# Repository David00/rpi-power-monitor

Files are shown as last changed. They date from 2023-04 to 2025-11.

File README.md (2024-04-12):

# Power Monitor HAT (for Raspberry Pi)

This project is a combination of custom hardware and software that will allow you to monitor your unique power situation in real time, including accurate consumption, generation, and net-production. The data are stored to a database and displayed in a Grafana dashboard for monitoring and reporting purposes.

This project is derived from and inspired by the resources located at https://learn.openenergymonitor.org. 

---

## Where can I get it?

I am offering DIY kits, factory-assembled PCBs, and a variety of current transformers to use with this project.

Please see https://power-monitor.dalbrecht.tech/ for more information.

---

## How do I install?

There are two main ways to install - either flash the custom OS image to your microSD card, or perform the manual installation process on your existing image. Both processes are documented here:

See [Software Installation](https://david00.github.io/rpi-power-monitor/docs/general/install-the-software.html#prebuilt-os-image) in the docs.

After installation, see the [configuration section](https://david00.github.io/rpi-power-monitor/docs/v0.3.0/configuration.html) in the docs for further information on setting up the power monitor.

---

## What does it do?

This code accompanies DIY circuitry that supports monitoring of up to 6 current transformers and one AC voltage reading. The individual readings are then used in calculations to provide real data on consumption and generation, including the following key metrics:

* Total home consumption
* Total solar PV generation
* Net home consumption
* Net home generation
* Total current, voltage, power, and power factor values
* Individual current transformer readings
* Harmonics inspection through a built in snapshot/plotting mechanism.

The code takes tens of thousands of samples per second, corrects for phase errors in the measurements, calculates the instantaneous power for the tens of thousands of sampled points, and uses the instantaneous power calculations to determine real power, apparent power, and power factor. This means the project is able to monitor any type of load, including reactive, capacitive, and resisitve loads.

---

## Documentation

https://david00.github.io/rpi-power-monitor/docs/general/index.html

---

## Contributing

Would you like to help out? Shoot me an email at github@dalbrecht.tech to see what items I currently have pending.

---

### Credits

* [OpenEnergyMonitor](https://openenergymonitor.org) and forum member Robert.Wall for guidance and support

* The `spidev` project on PyPi for providing the interface to read an analog to digital converter

---

### Like my project? Donations are welcome!



BTC:  1Go1YKgdxAYUjwGM1u3JRXzdyRM938RQ95

###### Last Updated:  April 2023

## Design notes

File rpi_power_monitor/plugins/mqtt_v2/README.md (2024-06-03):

# MQTT Documentation

#### Author: jplord, based on jmadden91 v1 implementation

## Purpose

The MQTT plugin allows you to export power monitor data to a MQTT-capable system. 

## Setup & Usage
You'll need to install the paho mqtt v2 client to use this plugin:

    pip install paho-mqtt>=2

The following configuration block needs to be added to the power monitor's `config.toml` file

```toml

[plugins.mqtt_v2]
    enabled = true
    host = "xxx.xxx.xxx.xxx"
    # Leave Username and Password "" if you are not using authentification
    username = ""
    password = ""
    prefix = "powermon"
    power_change = 5
    voltage_change = 3
    current_change = 1
    pf_change = 0.05
    refresh_rate = 5 # Refresh rate in seconds
    max_publish_seconds = 600

```

This plugin will send all measurements for all channels to the host specified above.
Alter power_change, voltage_change, current_change, pf_change to define how much variation in the values will trigger a publish
Alter max_publish_seconds to define how often values are republished regardless of variation

## Configuration options

    enabled

Needs to be set to true to enable the plugin.

    username
    password

Specify the required username and password for MQTT. Leave "" if you are not using MQTT authentification.

    prefix

Specify the prefix of the mqtt topic used to publish the values.

    power_change
    voltage_change
    current_change
    pf_change

Define these values to determine the required variation in power, voltage, current or pf that will force an MQTT publish of the new value if detected over a period of less than the configured max_publish_seconds.
For example, with a configuration of voltage_change = 3, if the voltage is stable at 122.00 volt and it drops to 118.00 volt over a period of time that is less than the configured max_publish_seconds, the 118.00 volt value will be published to MQTT immediately and as soon as detected as it is a delta of 4 volt which is greater than the configured 3 volt. The same would occur if 118.00 volt is measured and an increase to 122.00 volt occurs over a time period of less than max_publish_seconds.

    max_publish_seconds

Define this value to force a publish of the refreshed and most up to date values of all measurements regardless of if they changed of not.

    refresh_rate

How often this plugin will read current values from the samples provided by rpi-power-monitor.

## Support
Please post any issues or questions in the pull request thread located here:

https://github.com/David00/rpi-power-monitor/pull/124

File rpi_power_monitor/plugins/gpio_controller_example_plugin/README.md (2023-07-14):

# GPIO Controller Documentation

#### Author: David00

## Purpose
The GPIO Controller serves mainly as an example plugin to demonstrate how to build a plugin for this project.  However, it is a fully functional plugin, and as written, it will perform the following functions:

* Setup a single pin as an INPUT
* Setup a single pin as an OUTPUT
* Every 1 minute, set the output pin to 1/high if the power monitor's measurements are reporting a net-export of power.
* Every 1 minute, set the output pin to 0/low if the power monitor's measurements are reporting a net-import of power.

## Setup & Usage
This plugin requires RPi.GPIO to work. You can install it with the following command:
    
    pip install RPi.GPIO

The following configuration block needs to be added to the power monitor's `config.toml` file:

```toml
[plugins.gpio_controller_example_plugin]
    enabled = true
    pin_numbering_scheme = 'BCM'
    output_pin = 17
    input_pin = 27
    # Optional Config settings
    # log_level = 'INFO'  # This will override the logging level for the plugin, which normally gets the logging level from the main program.  
```

The input and output pins can use the "BCM" or the "BOARD" scheme. Here's the difference:

* BCM uses the "GPIO #" syntax: usually GPIO 1 through GPIO 26.
* BOARD uses the actual pin number on the header: 1 - 40

_See the "What do these numbers mean?" section on https://pinout.xyz/ for more info, and for a detailed header pinout map._

## Modifications
This plugin is a barebones example of how to write a plugin. Therefore, the actual logic of the plugin is fairly simple and may require modification to meet the needs of various users.  The entire logic of the plugin is contained inside [a `while` loop](https://github.com/David00/rpi-power-monitor/blob/develop/v0.3.0-plugins/rpi_power_monitor/plugins/gpio_controller_example_plugin/gpio_controller_example_plugin.py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) - this is where the decision is made to change the state of the output pin and is the likely place for you to expand the functionality of the plugin.

## Support
Please use [GitHub Discussions](https://github.com/David00/rpi-power-monitor/discussions) if you have questions about using or modifying this plugin.

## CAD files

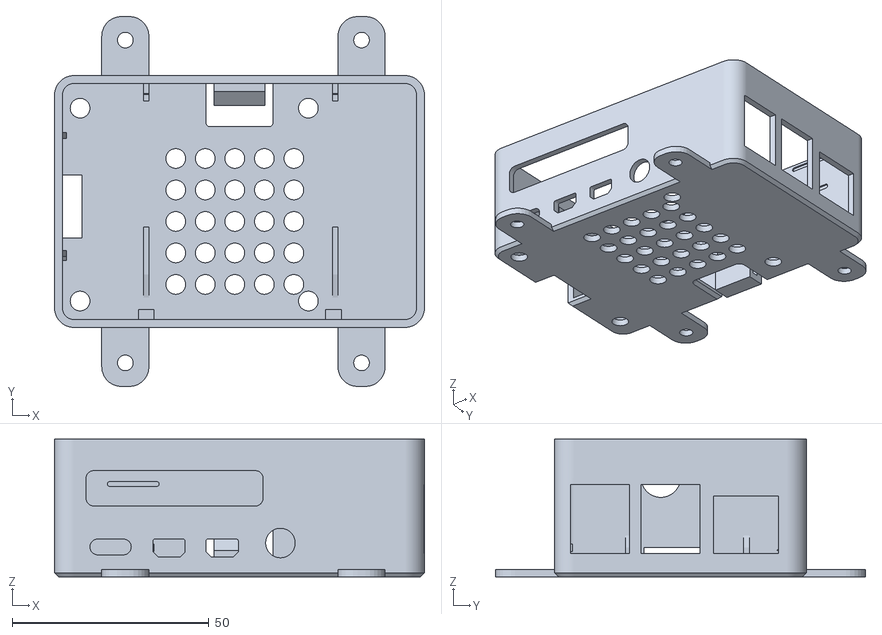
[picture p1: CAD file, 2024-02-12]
cases/factory-assembled-pcb/pi4/aircooled-jpl/factory-assembled-hat-pi4-box.stl
94.0 x 94.0 x 35.0

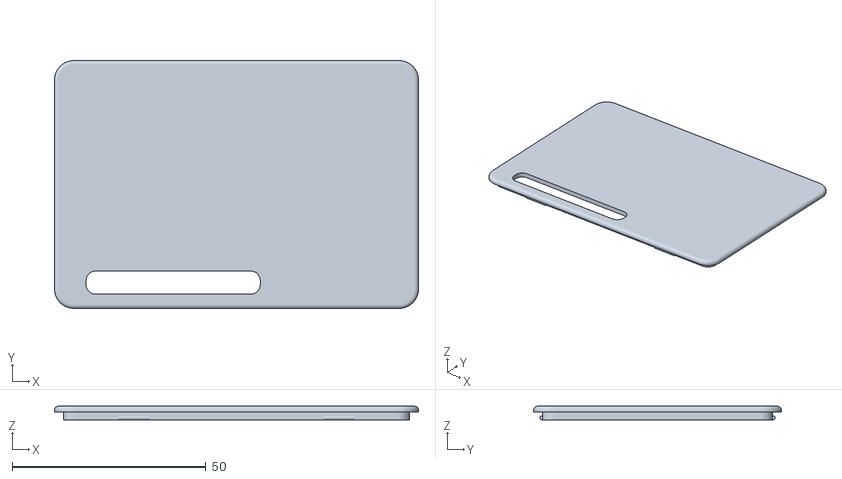
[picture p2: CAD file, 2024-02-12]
cases/factory-assembled-pcb/pi4/aircooled-jpl/factory-assembled-hat-pi4-cover.stl
94.0 x 64.0 x 3.50

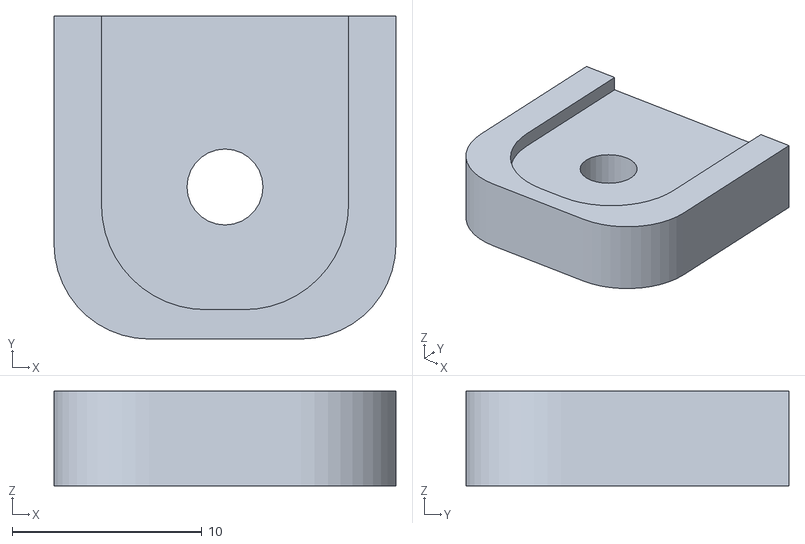
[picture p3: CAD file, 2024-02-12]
cases/factory-assembled-pcb/pi4/aircooled-jpl/factory-assembled-hat-pi4-standoffs.stl
18.0 x 17.0 x 5.00

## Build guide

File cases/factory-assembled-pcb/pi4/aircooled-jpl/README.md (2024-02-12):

# Case for Power Monitor HAT factory assembled for the Raspberry Pi 4 Model B

This is a case you can print for the factory assembled HAT running on a Raspberry Pi 4 Model B

---

## Features

The case includes holes for the standard Pi 4 Model B ports and in addition side holes that match those on the HAT. Also, the cover features an opening for the top screws of the terminal block.

Standoffs can be printed to raise the case off the surface it is installed on.

Tight clip fitment for the Raspberry Pi. It will be hard to remove the project from the case once clipped in place. Make sure the hat and any required heat sinks on the Pi are installed prior to fitting it into the case. It is also recommended to install the metal standoffs for the hat and insert the Pi without the hat installed.
---

## How to print ?

I have tested the build on Flash Forge Adventurer 4.

Supports are required for the case. Don't forget under the protruding clips near the USB C and audio port of the Pi. I used 4 sheels and 100% infill.

The standsoffs can be glued using a drop of crazy glue.

Case design based on https://www.printables.com/model/116513-another-raspberry-pi-4-case/files by guytas

###### Last Updated:  February 12 2024

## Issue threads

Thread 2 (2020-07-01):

I have got some issue

Riri45, 2020-07-01:
The adc which is mcp3008 is overheated, I am not using pcb, I use your early method at https://community.openenergymonitor.org/t/diy-current-monitor-on-raspberry-pi-my-power-calculation-isnt-accurate-help-please/13266/50 by using breadboard and gpio breakout broad, did the post installation setup until the "file written"

David00, 2020-07-01:
Hi Riri45, can you elaborate on the actual issue? What exactly isn't working with your breadboard circuit?

Riri45, 2020-07-01:
Sorry for not being clear at first
I have some questions
1.is it normal for the ADC overheat?
2.
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
The adc does not showing any data, I think I might damage my adc due to overheat

David00, 2020-07-01:
The MCP3008's datasheet says it is rated for operation up to 85 degrees Celsius, and I bet there is still quite a margin for operating in higher temps above 85C.  That's pretty warm! I'm not sure what you mean by overheat. Have you measured the temperature with an infrared temperature gun?

Make sure all your breadboard connections are correct, including the 4 required connections to the "control" side of the MCP3008 (power, ground, clock, and data).

Riri45, 2020-07-01:
sorry I forgot to ask is it okay if I'm using the opamp lm385 instead of lmV321

Riri45, 2020-07-01:
Problem solved the ADC is overheated due to my mistake connecting the t cobbler and the gpio cable wrongly at my raspberry pi, Thank you for sharing your knowledge, much appreciated

David00, 2020-07-01:
Great, glad you figured it out!

Riri45, 2020-07-12:
I would like to ask one more question if my input voltage is 230Vac compared to your input voltage 120Vac, at what are I should tweak in your phyton code?

David00, 2020-07-12:
I'm currently working on making the setup process easier for users to input values like this, along with the phase correction constants.  Right now there isn't actually a variable defined for source AC voltage. It's currently set as a ratio of your AC step down transformer multiplied by the ratio of the conditioning circuitry for the AC input (which is not very intuitive to figure out), but I've detailed the process below.

> I will be introducing a new "config.py" file for these values to be specified which should make the process easier, but it would be extremely helpful if you can do the following and confirm whether or not it works for your 230V input.

Find the ratio of your AC to AC step down transformer that puts out 9V AC. Ideally you should take an actual measurement of your A/C voltage source and then a measurement of your A/C transformer's output and do the following calculations based on that because the actual labels on the transformer itself usually aren't very accurate. Let's just say for this example that you measured 230V at the wall, and 9V at the transformer output:

1. Divide your transformer's output voltage by the grid voltage: 230/9 = 25.5556.
2. Multiply your answer by 11.  25.5556 * 11 = 281.111
    (11 is the ratio of the conditioning circuitry that the 9V AC source goes through on the PCB)

3. In [this line](https://github.com/David00/rpi-power-monitor/blob/master/power-monitor.py#L190) of the code, replace the `126.5` with `281.111`.

4. Uncomment [line 514](https://github.com/David00/rpi-power-monitor/blob/master/power-monitor.py#L514) so that the software prints the line voltage for every sample.

5. Save the file and restart your code - you should now see your line voltage readings printed out to your terminal window, and it should be in the area of 230V.  You'll still have to tune a bit for accuracy to improve the accuracy even further.

The accuracy tuning is a constant that is specified here [in line 39](https://github.com/David00/rpi-power-monitor/blob/master/power-monitor.py#L39).  You should compare a direct reading from your multi-meter to the printed Line Voltage message on the terminal. If the terminal is higher than the multi-meter, reduce the `AC_voltage_accuracy_factor` variable. If the terminal is lower than the multi-meter, increase the `AC_voltage_accuracy_factor`.

`AC_voltage_accuracy_factor` is just a constant that is multiplied by the calculated AC voltage. So, in my code, I needed a value of 1.075 for my AC voltage accuracy factor. That means my readings were a bit lower than my multi-meter, so 1.075 has the effect of increasing the calculated value by 7.5%.

Also, I have tried to find a 230V to 9V AC to AC transformer for 230V 50Hz grids and haven't found one. Can you please share the model number of the one you've acquired so we can help other users outside of the US?

Riri45, 2020-07-14:
sorry for a late reply, got some stuff needs to be done. https://www.aliexpress.com/item/4000276268327.html here is the link for the 230V/9V transformer.

i cannot access the influxdb and got some issue at the grafana resulting to this
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

David00, 2020-07-15:
Try to restart grafana with `docker restart grafana`.

If it continues to happen, can you share the output of `docker ps` and `docker logs grafana`?

Riri45, 2020-07-15:
Tried to run the influx docker but the `docker ps` showing this
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

Riri45, 2020-07-15:
Tried this too eventually resulting the same output
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

David00, 2020-07-15:
Something is running on your Pi that is using port 8086. You'll either have to figure out what it is and stop it, or change the port that the Docker influx container is binded to (and make the changes in the Python code to connect to the changed InfluxDB port).

Try this command on your Pi to see what is using 8086:

`sudo netstat -lntp | grep 8086`

Riri45, 2020-07-15:
I did and it shows this
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

Riri45, 2020-07-15:
managed to solved the influx issue but encounter with this
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

David00, 2020-07-17:
Have you ran the `power-monitor.py` file yet? [Running it for the first time](https://github.com/David00/rpi-power-monitor/wiki/Software-1.-Post-Installation-Setup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) will create the database.

Closed 2020-07-01.

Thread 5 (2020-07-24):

3 Phase Power

HarvsG, 2020-07-24:
Starting an issue to discuss the possibility (and perhaps track the progress) of supporting 3 phase power.

HarvsG, 2020-07-24:
We

1024jon, 2020-07-24:
+1 for me!

nannerbm60, 2020-07-24:
+1 for me too. Need mechanism for 3-phase monitoring with total consumption, total solar and net consumption

Nice work to date!

mario-correa, 2020-07-26:
+1

David00, 2020-07-26:
This is something I would love to work on, but I don't have a 3-phase supply to test and calibrate against.

If anyone has access to a lab grade 3-phase power supply and would like to assist with the development of 3-phase monitoring features, please send me an email at github@dalbrecht.tech.

fasmide, 2020-07-27:
This would be great and enable the project to be able to measure whole-house consumption across most European countries

As far as I know, the board would need at least 3 voltage measuring inputs for this to work...

i-am-snappy, 2020-08-04:
Just confirming that the 3 phase limitation is in software and not hardware? If that's the case, I'll be registering my interest on the board ASAP.

David00, 2020-08-04:
> Just confirming that the 3 phase limitation is in software and not hardware? If that's the case, I'll be registering my interest on the board ASAP.

The answer to your question is both yes and no. The code can be modified to _reasonably calculate_ 3-phase power usage, but there will be some small accuracy sacrifices. This is because, in the current single/split-phase implementation, there is only one voltage input sample, and the sample isn't just measuring the voltage level. It's also monitoring and capturing the harmonics of the voltage wave so that the current samples can be adjusted.

In a 3-phase system, each phase is **supposedly** offset by 120 degrees. With only one voltage input, we'd have to assume that this is true - we can't actually measure the offset to get its exact value. What if the real offset is 119.2 degrees? Or 121? These small tolerances will induce very small errors in the measurement and subsequent calculations. Yes, the variances I'm talking about here are a very small amount, but I am pointing it out just to say that in theory, it would not be as accurate as the current single/split-phase implementation is. I don't know how quantifiable this theoretical inaccuracy is, but I would take an educated guess and say that it would add an existing 1-2% accuracy variance.

In short, it's more of a software issue. The problem with assuming the phase difference and not being to measure it a rather small issue. Adding support for 3-phase monitoring with the existing hardware would still be much more accurate than the cheap monitoring systems out there that don't take **any** voltage samples. If you're able to assist with testing on a 3-phase system, I am definitely interested in working together to bring the software support for 3-phase to this project.

sethkaz, 2020-08-04:
I would say that you shouldn't worry tooo much about the phase offsets, as that should be pretty constant for a given supply (whether it be utility power or generated power).  What would be of interest is to see the relative voltages.  This would show if one phase is being loaded down more than the other phases.

This loading would also be interesting in a 2-phase system that is available in US households.  It's not separated by 120 degrees, but the difference in voltages on each leg can show if the loads on the house are put on evenly.  Arguably, with how little a given house draws (compared to a factory or warehouse), that delta isn't going to mandate changes by the given homeowner.

I would say from a HW perspective, you'd need to get a 3-phase transformer or 3 single-phase transformers, and wire them up.  I see that you're using a 9VAC external supply to currently measure the voltage.  You could use this method for the 3-phase, but you'd need to make sure that the supply doesn't regulate the voltage.

fasmide, 2020-08-04:
The phase offset is just one problem with having only 1 voltage measurement, there is no guarantee that the 3 phases are at the same voltage level, they are close, but can in various cases differ quite a bit...

For example, if a neighborhood for whatever reason, loads L1 more then the other L2 and L3 phases, or in my case where one phase is heavily loaded and the others are not.

Here is a screenshot from my own monitoring - I live in Denmark where all houses are installed with a 3-phased system by default:

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

at one point they are nearly 10v apart, under load this quickly becomes a few hundred watts

beadon, 2020-09-27:
+1 also very interested in this!

codefordough, 2020-11-15:
Also hope this can be developed. Would like to monitor a 480V 3-Ph feeder circuit that supplies a 75KVA transformer.

ariellevien, 2021-06-03:
Very interested in 3-phase. Our domestic supply voltage is WAY out of spec from the supplier (nominal 230V/ph, actual varies from 180V/ph to 240V/ph). I need to record all three.

David00, 2021-10-11:
Hi everyone, I'm happy to announce that I now have an early alpha version of software that should work for 3-phase systems. I haven't publicly released it yet and I would like some more people with access to 3-phase systems available to test. If you're interested in testing, please get in touch with me via email at "github at dalbrecht.tech"

The limitations mentioned previously in this issue thread still apply; specifically, the difference in voltages between the 3 phases will lead to an inaccuracy in the real power calculation. Accounting for the difference in voltages on each phase will require a hardware revision that I will explore in the future.

SCiunczyk, 2022-08-23:
Hi David,

have you got my email sent do "github at dalbrecht.tech" ? Or maybe it landed somewhere in your spam folder abyss ...

Slawek

David00, 2022-08-24:
@SCiunczyk Yep! Thanks for the reminder. I've been quite busy!

jt-eic, 2023-01-11:
Hello all, I'm rather new to the party and I just built my first (of possibly 3) of these monitor systems. I'd like to add my vote for 3-phase power here as well. Perhaps I'd also like to add that my interest in this isn't as much for 'consumption accuracy' as it is more for overall monitoring, and tracking historic measurements. In an environment where there is power, we need to know if we lost power and what to do next. (IE: sending alerts and beginning shut-down sequences). I know there are solid commercial systems for this type of thing, but I'm interested in how it all works and building custom DIY solutions.

SCiunczyk, 2023-01-11:
I have working 3-Phase setup (David send me the special version) I'm very happy how is working for last half year. Ask @David00  and check.

Cube3SGM, 2023-02-13:
Hi David,
I would interested in a 3 phase solution.  I have a smart meter on the supply already so I can get data in 30 minute intervals from the electricity supplier. I have 3ph coming in to the building which feeds a machine shop, this is also split into 3 x 240v single phase fuse boxes which feed the rest of the building. I would like to log data for the total consumption and the workshop consumption, as the workshop is rented to a 3rd party and not on a separate meter. Any other logging would be a bonus. Regards Simon

David00, 2023-09-10:
Hi folks, I'm going to go ahead and close this issue with the relatively recent inclusion of partial 3-phase support in the project earlier this year.

There's a discussion thread [here](https://github.com/David00/rpi-power-monitor/discussions/94) to provide feedback and ask questions, along with a link to the 3-phase setup instructions in the new docs:

https://david00.github.io/rpi-power-monitor/docs/v0.3.0/3-phase.html

Closed 2023-09-10.

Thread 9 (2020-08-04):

30A Current Transformers

nickcmeyer, 2020-08-04:
This could be a documentation suggestion or possibly expanded config parameters.

Currently using the ECS1030-L72 with a 75ohm resistor as suggested for 30A circuits.

The SCT-013 (100A) transformers needed a accuracy factor of 0.9. In comparison before I changed the accuracy calibration parameter for the ECS1030-L72 I get 82A for a 22A load measured by a clamp multimeter. That's a correction factor of 0.26. Initially this struck me as odd as I had interpreted the purpose of the accuracy calibration to only correct any variation between current transformers, burden resistors, etc. I realized the back end math isn't taking into account the size of the burden resistor or CT turns and just relying on this calibration factor. Looks like it's set up for the PZCT-02 10ohm and 1000/1 so a ECS1030 at 1000/.5 and 22ohm is 10% high like I saw. Voltage across the 75ohm burden resistor at 1000/.5 would therefore be 82/(75/(10*2))=22A, spot on.

I'm wondering if you might want to add config parameters for current transformer turn count, as well as burden resistor size, and do that bit of math in the back end. This way "calibration" would be more true to description and optional for those that don't have a clamp meter. Since you sent 1% burden resistors I'm guessing the accuracy would already be acceptable for many.

Also, kind of a side note, if there is a 30A CT on a 15/20A circuit is there any reason not to do the burden resistor math using the circuit breaker size as max? Obviously inrush current could go over 3.3v Vref but the ADC can obviously handle 5v+, although I couldn't find a spec for breakdown. Even with a 150ohm for a 15A circuit it looks like 30A of inrush would still be under 5v and slightly negative on the other half. This would realistically be the same ADC input range as a 75ohm on my 30A air conditioner circuit which has a 60A locked rotor current.

-Nick

David00, 2020-08-04:
Nick, thanks for opening this issue! I'm glad to have your feedback on this matter because it will definitely lead to me improving the project. In my personal deployment I only used 100A CTs, so it doesn't surprise me that this issue completely slipped by me. I do have some 20A and 30A CTs on the way to test with so I will be able to experiment with various changes to find a good long term resolution to this issue soon.

I can tell you have a solid understanding of what's going on, but for the sake of other's reading this in the future, I want to elaborate.  The burden resistor is chosen so that the current output by a particular CT can be turned into a voltage that has the potential to use the full range of the ADC input channel, which ranges between 0 - 3.3V. This is so that we can squeeze the most resolution out of the CT.  So, differenty rated CTs (ie, a 30A vs. a 100A, like in this case) will output the same values, but these values mean different things. A 30A CT putting out 2V at the ADC input is different than a 100A CT putting out 2V at the ADC input. But you're exactly right - the software is tailored for 100A CTs right now.

I've already been planning to introduce "profiles" for various CTs which would include a base configuration and calibration value to get the user in a relatively close range to being accurate.

> Also, kind of a side note, if there is a 30A CT on a 15/20A circuit is there any reason not to do the burden resistor math using the circuit breaker size as max?

I think this would only be safely accomplished if the CT is rated higher than the breaker of the circuit that it's monitoring. And by safe, I mean, not over-volting the ADC input channel and potentially damaging the ADC. The burden resistor calculation actually takes into account the peak _potential_ value of the CT, which is `CT rating * sqrt(2)`, and chooses a suitable resistor value that will keep the voltage output of the secondary transformer coil under 3.3V while at peak load. The absolute max voltage for an input channel is Vdd + 0.6, so that would be about 3.9V. However, the recommended input should be no more than Vref, which is 3.3V. Remember, the CT output voltage is biased +1.65V, so you really only have 1.65V worth of "resolution" to obtain from a CT.

nickcmeyer, 2020-08-05:
Sounds good, working on getting the services figured out and interface running but I'm sure the .26 calibration factor will work just fine.

Not sure how I missed the input/out max in the datasheet, it's right there now that I look at it today... I really should get off the computer earlier. Honestly I would have thought this would have been tolerant of higher and given that it isn't I'm actually more concerned given the possibility for inrush. As you stated the burden resistors are based on the math for peak not RMS but they don't take into account inrush. I think this has the possibility for issues even for 75ohm on a 30A CT on a 30A CB (ratios are the same for 150ohm on a 15A but my air conditioner on a 30A is a better example).

So looking at just the positive side of the wave, 30A produces 1.65Vpk plus the 1.65 bias for the full range 3.3v at the ADC. It only takes ~137% to exceed the 3.9v of the input. My air conditioner compressor has a running current of 13A, and a locked rotor current of 63A. (63*sqrt(2)*75)/2000=3.34Vpk. 3.3+1.65=4.95v or 1.65-3.3=-1.65v at the ADC. I may have to come up with a pair of Zeners or a TVS if I can find one that works to clamp across the burden resistor. Or I suppose do the opposite of my original proposition and go with a 33ohm resistor on the 30A CTs.

Out of curiosity I took a look at the trip curve for the Eaton BR circuit breakers in my panel. For a 15A breaker the the trip curve shows as much as 9-10x rated current for a 10ms interruption. So with a 1000:1 burden resistor sized for the CB (15A/150, 30A/75, 100A/22, etc) the ADC could still see 15.9v+1.65v=17.55v and -14.25v. Granted there is some validity to just popping a new ADC in vs making the inputs tolerant of someone sticking a fork in an outlet.

-Nick

David00, 2020-08-05:
> Sounds good, working on getting the services figured out and interface running but I'm sure the .26 calibration factor will work just fine.

Yes, the .26 calibration factor will work no problem because that factor is simply a linear scaling variable.

> Not sure how I missed the input/out max in the datasheet, it's right there now that I look at it today... I really should get off the computer earlier.

I know what you mean - I swear the answers only come out of the datasheet after the 10th read through it!! I should (and am trying to) end my nights earlier, so I won't be getting too much into your maths that you've shared. But, the 75 Ω suggested burden resistor will keep the CT's output voltage below 1.65V for up to ~42A.

Also, the CT core will eventually become saturated at higher and higher currents, so the maximum output value through the secondary winding will eventually flatten out. I don't know what the maximum output at core saturation would be, but the "linear" output nature of the CT will stop being linear at or very near the 30A mark.  A current of 60A through the conductor being monitored will **not** register an output that is twice the output of a 30A current.

David00, 2021-07-08:
I am closing this as it will be addressed in an upcoming major software redesign that I'm currently working on.

Closed 2021-07-08.

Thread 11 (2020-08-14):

Voltage tuning - AC multiplier seems to have no effect

jx, 2020-08-14:
I purchased the kit from you, and bought the 9v transformer you suggested.

I'm having an odd issue on the voltage tuning step. https://github.com/David00/rpi-power-monitor/wiki/Voltage-Tuning

Steps 1-6, i've measured the voltages, and edited the config file. My values are:
GRID_VOLTAGE = 124.2
AC_TRANSFORMER_OUTPUT_VOLTAGE = 10.4

When I get to steps 7 and 8, this is the output I get:

```
2020-08-14 18:06:24 :

+---------+---------+---------+---------+---------+---------+---------+
|         |   CT0   |   CT1   |   CT2   |   CT3   |   CT4   |   CT5   |
+---------+---------+---------+---------+---------+---------+---------+
|  Watts  | 548.882 | 538.409 | 530.817 | 532.487 | 542.351 | 548.233 |
| Current |  2.682  |  2.629  |  2.591  |  2.601  |  2.648  |  2.678  |
|   P.F.  |  0.915  |  0.916  |  0.916  |  0.916  |  0.916  |  0.916  |
| Voltage | 223.561 |         |         |         |         |         |
+---------+---------+---------+---------+---------+---------+---------+
```

The wattage numbers look absurd given nothing is connected. The voltage is also wildly inaccurate. But, carrying on, I got the multiplier, and in my case it's 0.5343. I add that to the AC line at the bottom, and my output is the same.

```
2020-08-14 18:07:50 :
+---------+---------+---------+---------+---------+---------+---------+
|         |   CT0   |   CT1   |   CT2   |   CT3   |   CT4   |   CT5   |
+---------+---------+---------+---------+---------+---------+---------+
|  Watts  |  557.58 | 547.525 | 539.154 | 540.746 | 550.063 | 555.691 |
| Current |  2.703  |  2.652  |  2.613  |  2.623  |  2.667  |  2.694  |
|   P.F.  |  0.916  |  0.917  |  0.916  |  0.915  |  0.916  |  0.916  |
| Voltage | 225.222 |         |         |         |         |         |
+---------+---------+---------+---------+---------+---------+---------+
```

I have absolutely no idea what could be wrong. I'm 99% sure I assembled the board right.

David00, 2020-08-14:
Hey Grey! I remember your order. It was kind of a while ago and there have been a couple of software updates since then - [one of which](https://github.com/David00/rpi-power-monitor/commit/84654d6d3f9d21b949d06b19ac241c3f757fa8b1) was directly related to the AC voltage calculation.  Let's first make sure you're running the latest software.  See the Wiki page [here](https://github.com/David00/rpi-power-monitor/wiki/Software-4.-Updating-the-Code). Since you're on the calibration section, I wouldn't worry about backup up `config.py` like the instructions say.

The `git pull` command will either say `Already up to date` or it will have a few lines of output as it pulls and updates your local version of the software. If it says it's already up to date, there may be an issue here which I'll definitely look into further.

jx, 2020-08-14:
Already ahead of you. Did fresh pulls today. Let me blow it all away and try one last time.

jx, 2020-08-14:
Ok. I blew it all away, fresh pull, and the multiplier part works! So I'll close this as user error!

David00, 2020-08-14:
Awesome, glad the re-install fixed it!

Closed 2020-08-14.

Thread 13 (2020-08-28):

Incorrect Capacitor Listing in assembly/schematic

rayder13, 2020-08-28:
Capacitor C4 in the schematic and component list on the assembly page lists C4 as 100nf but the footprint and image of assembled pcb on the assembly page indicate that it is a 1nf capacitor. Also L1 isn't mentioned in the assembly page anywhere. I'm still pretty new to anything beyond basic mcu projects so it may just be obvious to everyone else but the assembly page image seems to look like a wire link? May be beneficial just to clarify that on the assembly page.

David00, 2020-08-28:
Hi rayder13, thanks for opening an issue. Can you clarify exactly where you're seeing discrepancies for capacitor C4? I just looked through the Hardware Assembly page and I don't see any problems - the only image where C4 is shown is a top down view and you can't see the markings on it.

You're correct in observing that L1 is a wire link. The inductor L1 was in the prototype schematic just in case I found the PCB needing some additional signal filtering on the 3.3V supply.  It turned out that the circuit didn't need it, so a wire link is used in its place. It was one of those "just in case" sort of things. I'll update the Hardware Assembly page to mention this, but L1 will be removed from both the schematic and PCB in a future revision.

rayder13, 2020-08-28:
You may not be able to see the markings on the capacitor but the physical sizing of the 4 capacitors is noticeable. In the "Before you begin" section, the component table lists C4 as a 100nF Electrolytic which are the large box shaped caps, where the assembled pcb top down image shows C4 as the smallest cylindrical cap (In comparison to C6). And the op-amp circuit portion of the schematic also shows it as 100nF while C5 is 1nF.

David00, 2020-08-28:
Thanks for clarifying. Electrolytic capacitors are actually the can style ones in the picture. The yellow box shaped caps you're referring to are polyester/plastic film capacitors.
C4 is indeed an electrolytic (can style) 4x7mm 100nF / 0.1µF 50V capacitor.
C5 is also a electrolytic (can style) 4x7mm 1µF 50V capacitor.

They are the same form factor/footprint.

I took a look at the BOM that's linked on the Hardware 1 page and it seems to be missing the 100nF electrolytic capacitor. Now that I think about it, I used some 100nF capacitors I had on hand when I built my first few boards so they were never purchased/included in the BOM. I'll update the BOM to include them.
Here is the specific component for C4 for reference:
https://lcsc.com/product-detail/Aluminum-Electrolytic-Capacitors-Leaded_CX-Dongguan-Chengxing-Elec-0-1uF-50V-4-7_C45664.html

David00, 2020-08-28:
I am marking this as closed via eaedc6a that includes the specific component for C4. I think since it was missing from the BOM it was contributing to your confusion over the capacitor types.  We can continue discussion though if you need more clarification. Thanks again for opening the issue - it lead me to notice the missing capacitor in the BOM.

rayder13, 2020-08-28:
No that's fine. I just assumed the BOM was from when you ordered so I figured the assembly page was incorrect. It was just a combination of an oversight on your behalf and a lack of understanding on my behalf. Either way if it wasn't me then somebody else at some point would have been scratching their head trying to work out what was going on lol.

rayder13, 2020-08-28:
Don't forget to update the link on the Acquiring the Components page. It still points to the original 1.1 BOM.

Closed 2020-08-28.

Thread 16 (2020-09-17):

Raspberry Pi version

CathalOConnorRH, 2020-09-17:
I've bought the kit and have just received it but I have a question on the Raspberry Pi.
Would this work on the raspberry pi 1 for just monitoring the power values and grafana etc were hosted on another server ?
If not, Is there a minimum ram spec you think is needed for the raspberry pi?

Thanks.

David00, 2020-09-17:
I wouldn't recommend using the Pi 1, or Pi 2, or the original Pi 3. I haven't tested any of those, but my recommendation is based off of my experience using the Pi 3B+ and 4B. The 3B+ seems to be the minimum threshold for performance. The biggest concern is the CPU. It's quite CPU intensive because it's performing tens and tens of thousands of the calculations on the raw data per second. I'd imagine the database and Grafana dashboard only add a small bit of overhead when compared to the actual sensing and calculating of the raw data.

There's no harm in trying it on your Pi 1, though. I'd suggest running the software in debug mode so that it will generate a plot of the raw data. Debug mode doesn't require influxDB to be running. In the plot, you can see the actual waveform of the data. Just plug in the 9V AC voltage input, start the debug mode to generate the plot, and then view the plot (all documented [here](https://github.com/David00/rpi-power-monitor/wiki/Software-1.-Post-Installation-Setup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)).

The voltage wave should look like a smooth sine wave and the more peaks you can count, the better. The plot should have around 30 peaks for it to be considered fast enough for this project.  Also, the spacing between the peaks should be equidistant. This is a visual depiction of how regularly the Pi is able to execute the code and sample the data. Irregular sampling intervals (as indicated by varying amounts of space between peaks in your plot) would suggest the Pi can't keep up with the demand.

My recommendation is to use the Pi 4B 2GB version.

CathalOConnorRH, 2020-09-18:
Thanks for the detailed response.
I'll order a Pi4 but I'll give the Pi 1 a go and see if it would work out of curiosity.
I'll update this issue once I have an answer either way.

David00, 2020-09-18:
No problem!  Your question actually prompted me to look into something I've been wanting to do since I began this project, which I think will actually be useful for you and your Pi 1. It **might** even allow this project to work on the Pi Zero, but I don't want to get ahead of myself.

Yesterday I began converting the project to Cython. Basically, it allows me to offload all of the heavy calculations to C, which will run as a compiled extension of Python and provide a huge speed improvement. In the amount of work I did yesterday, I'm already seeing upwards of 50% improvements in speed.  I still have more optimizations to make, but it is looking promising for allowing lower-powered/older devices to run at least the sensory and calculation part of the project.

I have a busy weekend coming up so I don't think I'll have anything to share until sometime mid next week. I'll add a new branch to the repo with this new version of the project then with some instructions on how to get it.

kobuki, 2020-09-26:
@David00, great work on this project! I've just browsed through the huge OEM community thread where you detail every step of your work. I was thinking about making something similar this year - in an attempt to bring all calculations and bookkeeping of sampled data to the Pi, using pure Python tools and MCP3208 instead of the MCP3008. You kind of already finished something like that, nice! This alone shows that this is indeed possible.

Now the actual question, somewhat related to the above (If I should ask in a separate issue or bring the question to the OEM forum, please just say so). What is the total sample rate and the per-channel sample rate you can achieve with your setup - Python 3 and RPi 4B?

Also, instead of Cython, wouldn't it be more beneficial to use NumPy and/or SciPy to handle the heavy calculations? These great libraries already have native code bound to them in the package, for fully utilizing the underlying CPU. (Actually, with my planned project, I was to use them for the same purpose.)

David00, 2020-09-26:
@kobuki, thanks!! While the MCP3208 has a higher resolution, it also has a slower maximum sampling rate. You may be able to use it as a drop-in replacement for the MCP3008 but you'll have to reduce the [SPI clock speed](https://github.com/David00/rpi-power-monitor/blob/master/common.py#L15). The datasheet for the 3208 lists a max clock speed of 1.0MHz at 2.7V, whereas the 3008's minimum at 2.7V is 1.35MHz. Since the chip is running at 3.3V, the clock speeds can be run a bit higher, but I doubt you'll be able to run the 3208 at the same 1.75MHz clock that I'm running the 3008, and this will have a hit on the sampling rate.

I do want to create a separate issue to track the benchmarks, optimization ideas, and more. I like your idea of using NumPy instead of Cython - it would be interesting to compare the two. I've created a separate issue for this subject in which I'd like to move this optimization conversation to: #17.  Would you (kobuki) like to assist with a NumPy optimized fork of the project?

As for the original issue, I'm curious to see if @CathalOConnorRH tested the current version of the project out on the original Pi 1, but the current recommendation still stands at the Pi 3B or newer. Eventually, this recommendation will change when optimizations are finalized.

kobuki, 2020-09-26:
I've already ordered the PCBs from PCBWay, they should be here in a few weeks per usual. My hands are full with my job nowadays but I'll help with optimizations where I can. It's likely that using a lib with native code support like NumPy will require some major rework in how things are processed. I'll outline my ideas in the new thread.

WRT clock and ADC resolution. The MCP3208 is capable of 100 kSPS at 12 bits. In the other thread you mentioned an average sampling rate of 4-4.5 kSPS, and thus I think the limiting factor is not the chip but Python itself.

CathalOConnorRH, 2020-09-26:
@David00 I'll be testing the pi tomorrow all going well. I have the circuit built and should fine some time tomorrow to install and test.  Will let you know how it goes.

CathalOConnorRH, 2020-09-28:
Hi @David00 I've just gotten the pi disconnect and the header size is different on the older Pi. I'll just order a new one and use that instead.

Closed 2020-09-28.

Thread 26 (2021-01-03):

Documentation Clean Up

David00, 2021-01-03:
I've received feedback from a few people that the documentation can be difficult to follow along as it is sometimes unclear how to proceed after finishing a page. Thank you for all your feedback!

I'm opening this issue have something to reference commits to as I work towards improving the documentation.

If, at any time, you find something that is unclear or difficult to follow, please leave a comment here (even if the issue is closed in the future, feel free to reopen it), and I will address it.

clearlyunitended, 2021-01-09:
David,  I think it  would be worth-while mentioning that the CT's should be connected to the monitor board before clipping onto cables  - to avoid over-voltage on the ADC inputs.

David00, 2021-01-11:
Thanks @clearlyunitended, that is a great suggestion. I just updated this page in the Wiki:
https://github.com/David00/rpi-power-monitor/wiki/Final-Installation#installation-tips

David00, 2021-02-03:
All of the content files for the project documentation in the WIki is being moved to a branch titled `docs`.  This includes images, schematics, BOMs, and fabrication files.  I will be updating the links in the Wiki pages to reference the new branch, and then I will remove the docs folder from `master`. I understand this will break people's browser bookmarks, but it's needed to help keep things organized and easy to find.

corbolais, 2021-02-03:
In what regard should this be needed?

I've never seen a project use a doc branch for documentation. It's always a doc subdir.

Branches basically are intended for versioning the repository rather than structuring content.

I'd strongly suggest to revise this decision. On the long run it's going to be a hassle.
Just imaging having to switch branches back and forth for documentation and the rest of the repo.

David00, 2021-02-03:
There is no need to switch back and forth between branches for documentation because I do not intend for people to access documentation through the Git structure. Current documentation is hosted in the project WIki. The `docs` branch is used simply for hosting files that are linked from in the project Wiki.

When people clone the project per the installation instructions, they only clone the master branch.  If documentation were on the master branch, they would be downloading images with no context, old/obsolete schematics, old fabrication files, etc.  This wastes both network bandwidth and disk space, because having these files on disk serves no purpose when the Wiki is hosted online.

corbolais, 2021-02-03:
Why link from the wiki to obsolete content at all?

`git clone --depth 1` lets you download only the latest revision, BTW.

Maybe I'm missing your point. Just let me know. I'm wondering why obsolete content needs to be there in the repo.

David00, 2021-02-03:
I think obsolete was too strong of a word. Here's an example of why I need to keep... _old_... stuff. This project deals with hardware which is naturally going to change over time through major and minor revisions. I might be working on v1.3 of the PCB and, but people are still using v1.2 hardware.

When v1.3 is released, v1.2 doesn't become any less important - it just isn't the latest version anymore.  So, `git clone --depth 1` doesn't help to solve this because I'm not actually upgrading v1.2 files to v1.3 - I'm leaving v1.2 where it is, and adding new files for v1.3. People running v1.2 hardware may not be concerned with v1.3 schematics, BOMs, and fabrication files, just as people running v1.3 hardware aren't concerned with v1.1 or v1.2.  However, everyone needs access to the files relevant to their version of the project. This is why I am moving all content to a separate branch, so that when people clone `master`, they are only getting the application software needed to run the project and not all of the "extras".

The fact that the Wiki is a separate object outside the code repo also factors into this. What I mean is, when you clone the project, you don't get the Wiki. The "docs" branch (or folder) doesn't actually contain the documentation... it contains documentation _resources_, like images, fab files, BOMs, schematics, etc. So, having all these _documentation resources_ in a docs folder on `master` without having the actual accompanying documentation just doesn't make sense and is a waste of disk space and network bandwidth for those trying to deploy this project.

I don't really care that you haven't seen a project use a separate branch for docs, to be honest. (No snarkiness intended - it just... really doesn't matter). I am using the tools I have available the way that I see fit - maybe GitHub isn't the best place for what I'm doing, but this is where the project lives for now. If you have suggestions for an approach that would make documentation more accessible, organized, and maintainable, I would love to hear it!

corbolais, 2021-02-05:
I see the trouble you're trying to solve here.

The way you're trying to handle it is just different from what others chose to, so, fair enough.

Another way I've seen alot with hardware projects is to create entire new repos for each version. Or one more is to create new branches or use tags and releases.

Personally, I'd try the route of a repo instead of a wiki and start from there.

Closed 2021-07-08.

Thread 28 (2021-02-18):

Kw reading disparity

Rangeman0, 2021-02-18:
Hi David,

I recently built the kit from you and run all 6 CTs in my Australian 240v main switchboard. I got the 100A CT due to its wire size capacity but I would be better suited with a 60A to be a closer match to my power requirements - to this end I appear to be getting a disparity between the two dashboards I have installed in Grafana. The individual CT dashboard will show a constantly updated usage that is entirely correct (I have checked with clamp meters and a subpanel meter in my garage for relevant devices). When I swap dashboards to the Home power dashboard I appear to get a Kw usage for the day of almost exactly double my actual usage. I.e, if I consumed 10Kw in the day measured with my utility mains supply power meter or load tests of running the lights or AC my CT dashboard reflects this but the Home Power dashboard shows a 20Kw usage. I don't believe this to be a 100A CT range problem as I get almost exact readings to the utility meter when load testing.

I'm wondering if this is due to (somewhere in the Wiki) you discuss using a CT on your two legs of incoming power (I'm assuming you have 110v) which is different to the Australian standard of a single input of 240v.

I've had a basic poke at the code behind the Home power dashboard but it is far beyond my knowledge. I'm assuming it's a set of code to 'double' your usage based on having two inputs in the US?

All big assumptions on my side so I might just be doing something wrong. I'm happy to provide screenshots or such if that would help.

Not a big deal if it can't be done or if I'm doing something wrong as I'm extremely happy with everything and I'm very impressed at what it can show and how easy it was to build and install. It's just a convenience thing instead of dividing the readout on the Home Power dashboard in my head to see my daily usage.

Thanks,

Rowan

David00, 2021-02-18:
Hi Rowan,

Using this project on 240V is completely fine - in fact, you'll likely have better results than most of us North American folks because we have 60Hz electricity and most homes here have two phases (split phase) feeding our main electrical panels.

So, you said:
> The individual CT dashboard will show a constantly updated usage that is entirely correct

That's a great sign because the Individual CT Dashboard is the raw data. The Home Power Dashboard is a higher level analysis of the raw data. I am assuming you've already gone through all 3 steps in the [calibration section](https://github.com/David00/rpi-power-monitor/wiki/Calibrating-for-Accuracy) of the project wiki.

> and run all 6 CTs in my Australian 240v main switchboard

By default, the _Home Power Usage_ plot in the Home Power Dashboard is the sum of all 6 input channels. So, if you're monitoring your main 240V input from the utility provider in addition to individual circuits on your panel, the _Home Power Usage_ plot will be showing the power on your mains **plus** the other 5 CTs. The same goes for the _Home Consumption_ statistic panel.

I believe this is the problem you're running into, so I'll get right to describing how to fix it. It involves minor code edits in `power-monitor.py`, but don't worry, they're easy.

Find [this line](https://github.com/David00/rpi-power-monitor/blob/master/power-monitor.py#L476) in `power-monitor.py`.  This is the variable that is basically stored in the database and subsequently plotted in the _Home Power Usage_ plot.  See how it's defined as the sum of all the power calculations from each individual channel?

```
home_consumption_power = grid_0_power + grid_1_power + grid_2_power + grid_3_power + grid_4_power + grid_5_power + solar_power
```

Let's say - just for example purposes - that CT3 is the one that is on your main 240V incoming feed.  Your main incoming feed is how your entire home is powered, so it follows that the variable `home_consumption_power` should only contain the measurement from that single CT.  This means you'll need to change how `home_consumption_power` is defined by removing all of the other CTs that aren't measuring your 240V incoming main. The number in the `grid_#_power` variable represents the CT number.  So, you'll remove all of them that _aren't_ the specific CT that's on your mains. For example, if CT3 was measuring your main:

```
home_consumption_power = grid_3_power + solar_power
```

You can leave the `solar_power` variable because by default, it's zero, unless explicitly setup by following the net metering instructions.

You'll need to make a similar change in both the `home_consumption_current` and `net_consumption_current` variables a couple lines below the `home_consumption_power` variable above.

Make sure that you use a good text editor (like Notepad++) and also that the indentation level remains the same when making these changes because Python relies on indentations to interpret the code.

It's getting late for me now but feel free to provide feedback to my reply and I will see it tomorrow.

Lastly, thank you for opening this issue - it will lead to improvements in the Project Wiki setup instructions!

Rangeman0, 2021-02-18:
Hi David,

Made the changes to the power-monitor.py as you suggested this morning while I had breakfast. Very easy to do. I suppose if I had dug deeper I may have stumbled across it but thanks for your very detailed and prompt response.

I'll let it run while I'm at work and do some more testing this afternoon/tonight and see how the results go. I'm confident that this will indeed fix the problem (or my lack of attention).

Also, general note you may wish to add - This is in no way related to your circuit but may help a future user. I originally used a Samsung dual voltage phone charger 9v/5vdc to power the pi while building and coding which eventually gave me undervoltage errors.

This caused the pi to hang so I investigated and added a nightly reboot script I found online but still ended up with the pi freezing.

I swapped this Samsung to a USB C Google pixel charger and it has run fine ever since (still has the restart script running). It seems a high quality charger is required for consistency (and it also seems to have improved the Utility voltage reading consistency, which I didn't expect)

Thanks again and I'll update you once I have more data collected over the next few days.

Rowan

Closed 2021-03-02.

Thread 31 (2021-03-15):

Rpi monitor

vid-beatific, 2021-03-15:

David00, 2021-03-15:
I'm not sure what this is because there are no details. I'll close this for now and will delete at some point in the future if no details are added.

vid-beatific, 2021-03-15:
Sorry .. I wrote by mistake

Trimis de pe iPhone‑ul meu

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

Closed 2021-03-15.

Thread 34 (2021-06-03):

Current spike suppression?

altontoth, 2021-06-03:
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

Not so much as an issue specifically, as much as it is seeing if anyone has a clever method for eliminating spikes, either through software or hardware changes? I have a panel that I'm monitoring which includes a well pump, and every time the well pump kicks on, you can see spikes in all of the channels due to induction. CT2 is monitoring one leg of the pump circuit (240V pump). CT4 and CT5 are monitoring my mains, so I would expect to see a spike there, but the others (0, 1, 3) have nothing to do with the pump. Thoughts? I was thinking of using shielded wire, but I'm having a hard time finding it. I'm also considering buying a series of chokes. But I'm wondering if there's anything to do for it in software?

David00, 2021-06-03:
Wow, that's a neat capture - thanks for sharing!  How are your CT leads ran, and are each pair of CT leads twisted together?
A choke probably won't do very much good for this since they aim to reduce the impact from a specific frequency. This is likely capacitive cross talk from the conductor that is supplying the current to the pump motor.

Shielded wire might be your best bet - just pick up a shielded cat5e cable and cut one of the ends off, and attach your CT leads to the cutoff end. More details about using cat5e are [here](https://github.com/David00/rpi-power-monitor/wiki/Hardware-Assembly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) in the Wiki. The PCB's RJ45 jack accepts a shielded cat5e cable (with the proper shielded RJ45 connector) and will ground the cable's shield to the PCB, which should help reduce this type of noise.

It's also a good idea to keep the CT leads as far away from the current-carrying conductors in your electrical system. And try to **avoid** running the CT leads close to and parallel with the current-carrying conductors.

For software, you could try increasing Grafana's `GROUP BY` parameter to `30s` or more. This will essentially just average the data out and help flatten the appearance of the data when graphed.

Closed 2021-07-08.

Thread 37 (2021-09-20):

Current measuring will not read zero

chenhoulin6204, 2021-09-20:
So, I've done everything in the wiki, only difference is my board is completed on a bread board instead of a PCB.

Now, when I'm running the power monitor in terminal mode, I see there is always a current reading of about .5 Amps even when the CTs are not connected, in fact even if I ground CT_input to GND, there is still a .5 Amps reading. When there is actually load, the current measurement is roughly accurate.

This 0.5A messes with the power consumption calculation, because this means there will be a 100W consumption even when nothing is connected, and that's unacceptable. I don't know what is the problem, the ADC, the capacitors I used, the OpAmp, I do not know, please advise!
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

David00, 2021-09-20:
The breadboard is most likely the culprit here. Breadboards and jumper wires are prone to noise like crazy. It could also be that your sample rate is very low.

The values for current that you're seeing are simply the RMS values as calculated based off the raw sample data. So, if the values are wrong, something is wrong with your raw data.

You can plot the raw data and check the sample rate using [debug mode](https://github.com/David00/rpi-power-monitor/wiki/Software-1.-Overview#debug-mode).

Closed 2022-01-09.

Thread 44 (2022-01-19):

Is this project also avaible without the 9V AC transformer?

YoManGaming, 2022-01-19:
hello there, i live in the Netherlands and i want to use this project to watch my home power usage. Is it also possible to use this project without the 9V AC transformer (because it cant be shipped to here)?

David00, 2022-01-19:
Hello! Yes, you can use it without the 9V AC transformer, but you'll only be able to measure current from the CTs.

To fully utilize the features of the project, such as real power (Watts), energy (kWh), and power factor,  you'll need to acquire a 9V AC transformer that works with your grid.  The connector is a 2.1x5.5mm barrel jack. Feel free to send a link to a 9V AC transformer and I can confirm that it will work with the project or not.

YoManGaming, 2022-01-20:
Hey David, will this one work? https://www.amazon.com/inShareplus-Voltage-Transformer-100-240V-Connector/dp/B01GD4ZOI4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

David00, 2022-01-21:
No, that one won't work. It puts out 9V DC. It needs to put out 9V AC.

YoManGaming, 2022-01-23:
Does this work? https://www.amazon.com/Reliapro-ADU090150A2231-Adapter-Transformer-Straight/dp/B00B886CWS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

David00, 2022-01-23:
Yes - that's the exact same one I have available in my shop:
https://power-monitor.dalbrecht.tech/product/9v-ac-transformer-north-america-only/

Will it fit your outlets in the Netherlands? I thought they have the standard EU 2-prong 230V outlets over there.

YoManGaming, 2022-01-24:
I didn't think about that one😅. Yes, we have the standard 230V here. Then ill use the project only with the CT's. Can i just set the get_board_voltage() to the voltage im using?

David00, 2022-01-24:
> Can i just set the get_board_voltage() to the voltage im using?

If you did that, you'd only be able to get apparent power in Volt-Amperes (VA), which isn't really in line with what most utility companies charge you for. They charge you for the amount of real power you consume, which takes into account the phase relationship between the current and voltage waves in the electrical system.

You'd need one of these:
https://www.globalsources.com/AC-AC-adapter/AC-AC-adapters-1088369069p.htm

Perhaps you can find one within the Netherlands or within a European market? It is difficult for me to search for them as the results are mostly ads that are relevant to the North American 120V grid.

1v052, 2022-01-24:
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

You would only need to order 500 pieces ;)

Jokes aside, you should try to look on site slike eBay or Conrad electronics.
I found one on Ebay Germany which you could order, unfortunately the offer only runs for another 2hrs.
If it doesnt sell you could simply contact the seller and offer to buy it.

https://www.ebay.de/itm/313837031207?hash=item4912250f27:g:-r0AAOSwUvldEk-O

YoManGaming, 2022-01-24:
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

The problem is that i don't want to use this to monitor my home usage (like i said earlier). I didn't say this because i already knew how to use the code on the boat. It is needed for a project on a solar boat. The problem is then that i need to run it on batteries. I can run the raspberry pi on power banks, but measuring voltage is an other problem. You got a solution for that?

David00, 2022-01-25:
> hello there, i live in the Netherlands and i want to use this project to watch my home power usage.

> It is needed for a project on a solar boat.

Which is it?

It sounds like you need a DC monitoring system for your boat. This project is for AC power systems only and is intended for home use, not marine use (though if your boat has a DC to AC inverter to supply 120V or 230V AC, you can use it to measure the AC output of the inverter).

> You got a solution for that? edit: can i send everything (the PCB and the CT's) back if my project doesn't work?

Unfortunately, no.

Closing the issue as this has gone off topic but feel free to reopen if needed.

Closed 2022-01-25.

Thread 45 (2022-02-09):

Phase calibration does not work even with the correct kernel version

chenhoulin6204, 2022-02-09:
So, I've followed the setup instructions, the only difference is I remade the circuit on a breadboard and used some bigger capacitors.
The current transformer I used is YHDC SCT006, the burden resistor is 22 Ohms.

The issue is, when I am doing the phase calibration, even with the correct kernel version (4.19.118-v7l+), the results are still larger than 1.x. I have attached the results from your program's debug mode and phase calibration mode, please help!
(The sampling rate reported by the debug mode is around 28 KSPS, is that normal? I don't know... I am using Raspberry Pi 4B with 4GB ram)
[phase_calibration_problem.zip](https://github.com/David00/rpi-power-monitor/files/8029266/phase_calibration_problem.zip)

The load I used was an electric heater and its power factor is 1.00, confirmed by a store-bought power meter.

I have also attached photos of my setup, I am clueless what to do next... Any help is much appreciated, thanks a lot.
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

chenhoulin6204, 2022-02-09:
Hi,

1. The R0 is here:

I am only using one CT, so R1-R3, R8-R9 are not connected. R0 is at 22Ohms. The LMV321 is outputting 1.65V but my problem was I connected one of the CT’s feet to GND, I have now correctly connected it to the Vbias.
2. I’ve used a load resistor to make the AC input now 10V, but it is still not working well. R4 is 9.9k and R5 is 99.8k Ohms as measured so I think the values are correct, but when I measure the AC voltage between R4 R5 and GND, I got 0V instead of the expected 1V, I suspect either the ADC is drawing too much current or something wrong with the GND_break? I am currently using a 4.7µF electrolytic capacitor to ground it to GND.

The problem now has changed, the phase calibration does not give me 2.x anymore but the results are inconsistent, the value fluctuates. Also in terminal mode, the unconnected CTs are showing weird results, although I am able to complete the accuracy calibration now, something still seems wrong. I’ve attached the updated initial test and phase calibration results, could you take a look please? Thanks a lot for your time!

Sent from Mail for Windows

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

David00, 2022-02-10:
Can you add the attachments on GitHub directly? They don't come through via email.

> The problem now has changed, the phase calibration does not give me 2.x anymore but the results are inconsistent, the value fluctuates. Also in terminal mode, the unconnected CTs are showing weird results, although I am able to complete the accuracy calibration now, something still seems wrong.

Don't worry about the values until the circuitry is fixed.  You'll still be very susceptible to noise on the breadboard though, and you can already see that noise in the original debug plot on the other CT channels that you don't have connected to anything.  Not much you can do about that on a breadboard.

chenhoulin6204, 2022-02-18:
Hi, sorry for the delay. I can complete the accuracy calibration now, but I still think the results are dodgy, since the phase calibration value is inconsistent.

The debug test result and phase calibration result are attached, what could be the problem please? Is it because of the noise? Could using shorter cables or better cables solve this problem? Or is it the capacitors I used are of poor quality? I have no idea...

Please educate me, thanks a lot
[new_results.zip](https://github.com/David00/rpi-power-monitor/files/8094113/new_results.zip)
!

David00, 2022-02-18:
The new `initial_test.html` looks pretty good now actually.  The only thing I'd recommend is trying with a higher powered resisitve load so that the current samples coming in are more in the middle of the range of the sensor.

If you don't have a larger resistive load, you can use the loop trick to multiple the amount of current that the sensor sees:
https://github.com/David00/rpi-power-monitor/wiki/Phase-Correction-Procedure#current-multiplication-example

Closed 2022-03-19.

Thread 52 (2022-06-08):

How to correct measurements for 240v circuits, i.e. air conditioner, range, dryer, etc

pablomarquesmendez, 2022-06-08:
David

first of all thank you for this project.

How should I go about If I want to measure 120v and 240v circuits with the same pi hat?

Are there specific settings on the config.py if, for example, I am measuring a single 15Amps breaker on CT-0 and a 60Amps 240v circuit on CT-1.

Regards

Pablo

David00, 2022-06-08:
Hi Pablo, there are a couple of ways you can do this for 240V circuits, depending on the appliance and your tolerance for accuracy.

1) You can double the measurement from a single sensor to get an reasonable approximation for a 240V circuit, or
2) You can use another current sensor to measure the other phase of the 240V circuit, and then sum the values together before sending them to the database.

Option 1 is easier and is fully supported. Option 2 requires some code modification to sum the measurements before adding to the database.

For option 1, see this part in the wiki:
https://github.com/David00/rpi-power-monitor/wiki/Solar-Integration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

For option 2, the general idea is to add the values from the two sensors together, similar to how I've done it here in [this line](https://github.com/David00/rpi-power-monitor/blob/master/power-monitor.py#L476), and then create a new measurement in the database.  Getting a new measurement written to the database ([this function](https://github.com/David00/rpi-power-monitor/blob/04c88ec8a1b08afdbbc6567e98f0f2f100bc2749/influx_interface.py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)) currently isn't very easy or user friendly, and this is something I've been thinking of adding lately. So, if you want to try option 2, I can make some changes to make it easier to do this.

pablomarquesmendez, 2022-06-08:
David

Thank you for the quick reply.

I tried option 1 and it is not giving me good results.
I edited power-monitor.py and modified it following the instructions:
    results = {
        'ct1' : {
            'type'      : 'consumption',
            'power'     : real_power_1 * 2,
            'current'   : rms_current_ct1 * 2,
            'voltage'   : rms_voltage_1,
            'pf'        : power_factor_1
        },

Even after doing the phase correction step and entering the ct_phase_correction in config.py, it is reading huge amp numbers.
With the stove running (pure resistive load), the program reports 45Amps. I measured it with my multimeter and it is really taking about 10.7 Amps.

What could be the issue here?

Thank you

David00, 2022-06-09:
The calibration process takes two steps - one is the phase calibration, and the other is accuracy calibration.  The phase calibration corrects the timing between samples, and the accuracy calibration corrects the amplitude of the readings to match the sensor value you have.  Did you do [step 3](https://github.com/David00/rpi-power-monitor/wiki/Calibrating-for-Accuracy#step-3-final-accuracy-calibration) of the calibration process?

If not, you'll have to remove the `* 2` from the power and current results, and then do the accuracy calibration for the channel in question.

I came to this conclusion because the [software assumes](https://github.com/David00/rpi-power-monitor/blob/master/config.py#L51) you're using a 100A sensor, and since I believe you ordered all 60A sensors, your actual readings should be around 60% of what you're seeing now.  And 60% of 45A is 27A, and if that was the doubled measurement from CT1, then we can half it to get pretty close to your handheld meter (27A / 2 = 13.5A). But, this is just ballpark based on an assumption (and the uncalibrated CT1 is being doubled, therefore increasing the error) so the accuracy calibration step will really bring the reading closer.

JeromeThiv, 2022-11-24:
Hi David,
I followed option1 for my 240v circuit of the water heater.
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

I tought that the result would simply be a multiplication by 2 but the 1.6kw consumption became a 2.15kw :

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

When I zoom, i see that the measure are oscillating between 1.6 and 3.2, with an average of 2.15 :
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

Did i miss something ?

David00, 2022-11-25:
Hi Jerome, if you're on the latest version of the software (v0.2.0), you'll have to do a `pip install .` to get the values in config.py to reflect in the measurements. So, try:

`cd ~/rpi_power_monitor && pip install .`

Then, restart the software and you should see the changes take effect.

JeromeThiv, 2022-11-26:
oops yes thank you. I was only restarting the systemcl process.

Closed 2022-09-28.

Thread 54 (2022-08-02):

Non Linear calibration?

vulture2600, 2022-08-02:
Hey David,
First of all, this is an awesome project and my HAT is off to you! (pun very...VERY much intended).

I do have a question about final calibration. If noise induced on the CT shows a value above zero when not even clamped around a wire that has current flowing, wouldn't that imply a non-linear scaling factor? Maybe in the future you could make it possible to graph several values compared to a clamp meter and scale accordingly?
Even 3-5 points on a graph would make this quite a bit more accurate.

Thanks again for all you work!

David00, 2022-08-04:
Hi @vulture2600, thanks!

The challenge with noise coming in is that it could be coming from several different places. Most often, I think, is that the CT wire acts as an antenna and picks up surrounding fields.  It gets a little bit complicated for _how_ those values make their way up the stack and get presented to you, primarily because the calculations are all done using a RMS technique on a batch of 2000 samples from each channel. So, it could be one big spike that happened in a batch of samples, or a steady stream of noise that's always there in every sample.

When the noise is caused by big spikes, adjusting the sampling technique to shrink the batch size and build a moving average would help reduce the impact of spikes.  If it's a steady stream of noise, it should be calibrated out with a scaling factor. But, in either case, having a hard cut off for low readings has worked as a "software" filter.  Here's an example in the code that currently only checks the `solar_power` variable:
https://github.com/David00/rpi-power-monitor/blob/master/power-monitor.py#L461

You could implement the same thing by checking the `grid_#_power` variables and setting them (and the amperage & PF) to 0 if they fall under a threshold of your choosing.

What are you thinking regarding graphing points compared to a clamp meter? I don't think I follow what you're asking with that point.

vulture2600, 2022-08-05:
Hey David,
Thanks for the response.

To clarify my question, If I clamp the CT around a grounded wire, I should show zero amps. Induced noise makes it show a non zero number, around an amp or so. My clamp meter should also show zero. When I clamp the CT around another wire along with my clamp meter, I can calibrate the scaling factor so that they show the same amperage. The problem is when I turn on more devices, like a few air conditioners, the amperage on my clamp meter will show 20a for example, but the readings from the CT might be a few amps off in either direction. My proposal then, is to have the user take several samples at known values with a clamp meter and enter them in, and then have the software calculate scaling factors as a non linear curve instead of a hard value. It might be difficult for most people to get a sample above 20 or 30 amps, as a lot of things would all have to be running at the same time. Those with electric water heaters or dryers might have an easier time with higher current loads available and easily accessible.
So to clarify:
1) user reads 0 amps with clamp meter, user enters 0.
2) user reads 3 amps, user enters 3.
3) etc etc as high up as you can go, maybe like 5 data points.
4) software calculates a scaling curve that roughly follows the data points and extrapolates up to 50 or 100 amps.

Does that make more sense?

vulture2600, 2022-08-05:
David,
This is my clamp meter:
https://www.homedepot.com/p/Klein-Tools-400-Amp-Digital-Clamp-Meter-AC-Auto-Ranging-with-Temp-CL220/312649913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

I'm going to "borrow" a Fluke from work and see how far off they are from each other.

David00, 2022-08-07:
Yes, that makes sense now. I've tried to stay away from extrapolating smaller measurements up because that can introduce errors that multiply in magnitude the higher up you go.  Also, the sensors themselves are not exactly linear.  They're usually fairly linear between 5% and 100% of the rating, but outside those bounds, they're not.

The "[loop trick](https://github.com/David00/rpi-power-monitor/wiki/Phase-Correction-Procedure#current-multiplication-example)" of tricking the sensor (and your handheld meter) into seeing more current than is actually being consumed helps get the measured current into the sensor's linear zone and get a good calibration.

That is a good meter to use, and I'm interested to see how the Fluke compares!

David00, 2022-09-28:
Hey @vulture2600, how'd your testing with the Fluke go?

vulture2600, 2022-10-01:
I never actually tried the Fluke. Maybe this time around i will!

Closed 2022-11-13.

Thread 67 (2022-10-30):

Phasecal below 1.xxx

ejg3855, 2022-10-30:
I am having some trouble with phasecal values and my CT leads, I have checked the obvious with the system running as a service and that seemed to improve it a bit but still seeing values over 1.xx

I did purchase all the hardware from you and I think I have all the resistors installed in the correct locations.

I am seeing values recommended at :

2022-10-28 23:42:35 : Wave 1/3 results:
2022-10-28 23:42:35 :  Best PF: 0.036897026844769185 using phasecal: 1.5187898946333451
2022-10-28 23:43:10 : Wave 2/3 results:
2022-10-28 23:43:10 :  Best PF: 0.031783049466366946 using phasecal: 3.2677097966075936
2022-10-28 23:43:44 : Wave 3/3 results:
2022-10-28 23:43:44 :  Best PF: 0.030424070733198246 using phasecal: 4.492907124990358
2022-10-28 23:43:44 : Please update the value for ct1 in ct_phase_correction in config.py with the following value: 3.09313561
2022-10-28 23:43:44 : Please wait... building HTML plot...
2022-10-28 23:43:47 : file written to CT1-phase-correction-result.html

Also where is it writing these html files to I can't seem to find them in any of my pi directories.

David00, 2022-10-30:
HI @ejg3855, what model Pi are you using?

Did you install using my custom OS image, or by following the manual instructions?

Can you generate and then share a debug plot? Run `python3 power-monitor.py debug "Test"`, and then grab the chart by going to `http://<your Pi's IP address>/Test.html`.

The HTML plots go into `/var/www/html`, but it's easiest to get them through a web browser just by navigating to your Pi's IP address.

ejg3855, 2022-10-30:
@David00 thanks for the quick reply.

I get an error with the debug test

`pi@powermon:~/rpi-power-monitor $ python3 power-monitor.py  debug "Test"
2022-10-30 17:38:42 : Finished Collecting Samples. Sample Rate: 30.75 KSPS
2022-10-30 17:38:42 : Building plot.
Traceback (most recent call last):
  File "power-monitor.py", line 692, in <module>
    plot_data(samples, title, sample_rate=sample_rate)
  File "/home/pi/rpi-power-monitor/plotting.py", line 37, in plot_data
    ct0 = samples['ct0']
KeyError: 'ct0'
pi@powermon:~/rpi-p`

David00, 2022-10-30:
It looks like you're running an older version of the software - can you try to update? Instructions here:

https://github.com/David00/rpi-power-monitor/wiki/Software-4.-Updating-the-Code

David00, 2022-10-30:
Thanks, can you also attach the `CT1-phase-correction-result.html` file?

I think this situation happens when the PF is already incredibly good, which we can determine by looking at the phase correction result plot.

ejg3855, 2022-10-30:
lets try this:

[CT1-phase-correction-result.html.pdf](https://github.com/David00/rpi-power-monitor/files/9896745/CT1-phase-correction-result.html.pdf)

David00, 2022-10-30:
I can't quite zoom in to that like I can with the HTML file - can you attach it? Just go to File -> Save in you web browser when you're looking at the plot, then you'll get the actual HTML file.

ejg3855, 2022-10-30:
github doesnt seem to support html attachements.
[CT1-phase-correction-result.zip](https://github.com/David00/rpi-power-monitor/files/9896781/CT1-phase-correction-result.zip)

David00, 2022-10-30:
Ok, thanks! In that specific plot, there is essentially no data for CT1. Was the load turned on when you ran that phase correction, with the sensor measuring only the hot wire in the load's power cable (or the hot wire in the electrical panel?)

ejg3855, 2022-10-30:
lets try this.
[take 2 ct1 and ct2.zip](https://github.com/David00/rpi-power-monitor/files/9896926/take.2.ct1.and.ct2.zip)

David00, 2022-10-30:
Hmm, the current wave is looking very strange:

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

What is the load that you're measuring? Can you try testing on different input channels to see if the current waveform looks the same?

ejg3855, 2022-10-30:
It's a heat gun, was the only highish resistance load I have. I've done the test on 1/2 and posted the results above. I can try again again with 3/4. I have the solid cat5 wiee connected to the red from the CT lead.

David00, 2022-10-30:
Ok. The fan in the heat gun might be messing with things slightly, but I don't believe it would be producing a current waveform like what we're seeing. I saw that channel 2 had the same issue.

While checking 3 and 4, can you also share a picture of your assembled PCB? I should be able to check to see if it's assembled right.

ejg3855, 2022-10-30:
[ct3-4.jpg.zip](https://github.com/David00/rpi-power-monitor/files/9897049/ct3-4.jpg.zip)

i was thinking exactly that and included a photo

David00, 2022-10-31:
The board looks good - I don't see any issues there.  It might just be heat gun - do you have any other high power sources to test with? If not, I can run the phase calibration for that sensor and share the value for you to plug in.

ejg3855, 2022-10-31:
I have 2 200a sensors and 2 60a CT sensors. What other things do you suggest for high draw? I have a old school 200amp battery charger?

David00, 2022-10-31:
For the calibration part, a large halogen light bulb is ideal, because it's pretty high current draw, and also purely resistive.  Your heat gun is good for measuring a high current, but the motor in it throws some inductive characteristics into the current waveform.  But still, it shouldn't be reporting a wave form like what we're seeing, so it must be something else.

Can we try reducing the clock speed in `common.py`? Let's change `spi.max_speed_hz = 1750000` to `spi.max_speed_hz = 1000000`, and the generate a new debug plot with it measuring your same heat gun load?  I'm suspecting that the ADC might be faulty and reducing the clock speed might help determine that.

ejg3855, 2022-10-31:
reduced the sample rate and attached.
[Test.zip](https://github.com/David00/rpi-power-monitor/files/9905317/Test.zip)

David00, 2022-10-31:
Thanks - that's really strange that all channels - except for the AC voltage channel - are showing the same type of distorted waveform. I think the ADC in your kit might be faulty. Can you shoot me an email at github@dalbrecht.tech and I'll send out a replacement?

ejg3855, 2022-11-05:
Replaced the ADC not seeing much change.

Would it benefit to rebuild
[Test.zip](https://github.com/David00/rpi-power-monitor/files/9944737/Test.zip)
 the pi image?

I am just trying to create a logical path before I go and wholesale change the board.

David00, 2022-11-06:
Before changing the board, have you tried all the sensors too? We haven't really looked into the possibility of a faulty sensor yet so I'm thinking that might be a good easy step before replacing the board.

ejg3855, 2022-11-06:
I can try again. I'm suspect of my LAN cable connections at this point. Not sure what else it could be.

ejg3855, 2022-11-07:
I confirmed the sensor were corrected to the LAN properly. then I removed one of the leads and soldered it right to the board on CT5. I think I got the pins correct from looking at the bare extra board.

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

`thon3 power-monitor.py phase

Which CT number are you calibrating? Enter the number of the CT label [1 - 6]: 6

#------------------------------------------------------------------------------#
# IMPORTANT: Make sure that current transformer ct6 is installed over          #
#            a purely resistive load and that the load is turned on            #
#            before continuing with the calibration!                           #
#------------------------------------------------------------------------------#

Continue? [y/yes/n/no]: y
2022-11-07 18:36:06 : Please wait while I read ct6 and calculate the best PHASECAL value. This can take a few minutes, so please be patient.
2022-11-07 18:37:28 : Wave 1/3 results:
2022-11-07 18:37:28 :  Best PF: 0.8174227659750949 using phasecal: 1.4888637335882218
2022-11-07 18:38:49 : Wave 2/3 results:
2022-11-07 18:38:49 :  Best PF: 0.8011874789909631 using phasecal: 2.3067227440403673
2022-11-07 18:40:11 : Wave 3/3 results:
2022-11-07 18:40:11 :  Best PF: 0.6948684263975088 using phasecal: 4.537836196240262
2022-11-07 18:40:11 : Please update the value for ct6 in ct_phase_correction in config.py with the following value: 2.77780756
2022-11-07 18:40:11 : Please wait... building HTML plot...
2022-11-07 18:40:15 : file written to CT6-phase-correction-result.html`

David00, 2022-11-08:
Hmm - is that with a different sensor, or the same one? The current sensor trace in the CT6-phase-correction is still showing that same odd trace, so if it's a different sensor, it's not the sensors.

Another option - can you try with a different load (like an incandescent lightbulb) and use the [loop trick](https://github.com/David00/rpi-power-monitor/wiki/Phase-Correction-Procedure#current-multiplication-example) to multiply the current flowing through the sensor, and then generate a debug plot? I'm suspecting it might be the test load that you're using.

ejg3855, 2022-11-08:
more promising results with my percolator.

`2022-11-08 16:56:02 : Wave 1/3 results:
2022-11-08 16:56:02 :  Best PF: 0.999297609996258 using phasecal: 1.3488501525493075

2022-11-08 16:57:23 : Wave 2/3 results:
2022-11-08 16:57:23 :  Best PF: 0.999032581248988 using phasecal: 1.4482316150707089

2022-11-08 16:58:44 : Wave 3/3 results:
2022-11-08 16:58:44 :  Best PF: 0.9989602901343453 using phasecal: 1.4647194142493882
2022-11-08 16:58:44 : Please update the value for ct6 in ct_phase_correction in config.py with the following value: 1.42060039`

[CT6-phase-correction-result.zip](https://github.com/David00/rpi-power-monitor/files/9963459/CT6-phase-correction-result.zip)

David00, 2022-11-08:
Yep, that looks much better! The current waveform in the plot looks good now, and the phase-correction-result plot looks great too.  So, this might have just been due to your heat gun!

ejg3855, 2022-11-08:
Im still meeting a challenge with he Cat5 connector at the moment. Working on doing a bit of diag on it.

David00, 2022-11-08:
They can be tricky... here's a note in the Wiki about the cat5 connector... hopefully it helps!

https://github.com/David00/rpi-power-monitor/wiki/Hardware-Assembly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

ejg3855, 2022-11-08:
It seems to be all working now, thanks for the assistance. You want the
extra parts back?

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

David00, 2022-11-08:
Great! You're welcome, and no, feel free to keep them :)

Closed 2022-11-08.

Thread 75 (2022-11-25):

(PR Welcome) Move calibration/custom settings out of config.py to a TOML config file

David00, 2022-11-25:
There are two problems that stem from having user-inputted config settings into [`config.py`](https://github.com/David00/rpi-power-monitor/blob/master/rpi_power_monitor/config.py):

1.  The recent refactor that converted the power_monitor into a module (#62) allows the code to be installed with Pip via the included setup.py file.  When pip installs the code, it compiles the python source into bytecode, which means the module will no longer use the contents of config.py - instead, it uses the compiled version of config.py from the latest pip installation. Essentially, changing a value in config.py requires reinstalling with pip.

2. The config.py file is a git-tracked part of the codebase, and making changes to your local version means git will want you to do something with those changes before you can interact with the upstream codebase again. The current upgrade instructions rely on the end user to use git stash to store their changes, which is unnecessarily complicated for those unfamiliar with git.

Specifically, the following user-facing variables should be moved to TOML configuration file:
* GRID_VOLTAGE
* AC_TRANSFORMER_OUTPUT_VOLTAGE
* db_settings
* CT_PHASE_CORRECTION
* ACCURACY_CALIBRATION

The necessary code to read from the TOML and apply the settings upon startup will also need to be introduced and tested.

The TOML file should also have a version defined in it to help control compatibility with future code changes.

David00, 2022-12-07:
Also, add a cutoff threshold for users to specify at what value they want to ignore any readings.

David00, 2023-01-16:
I've started working on this issue.

Cube3SGM, 2023-02-07:
Hello, I have a similar problem related to the config.py when setting up for the calibration.

After modifying the config.py (236v and 10.1v) I am unable to successfully complete "pip install" I receive the message
Defaulting to user installation because normal site-packages is not writable
ERROR: You must give at least one requirement to install (see "pip help install")

I have replied in #83 but realised that this is a closed discussion, not sure if any one would see it!  Sorry if I have confused things by cross posting!

Any help appreciated, Regards Simon

Cube3SGM, 2023-02-09:
Hello David,

Really appreciate the fast response, you were absolutely spot on, I had missed the period. Sorry for the silly mistake.

Unfortunately I have run into another issue when setting it to run as a service.  I will give a quick description of the issue here but if you would like me to start another thread then let me know.

Created the service file, modified it as per instructions (Note. The Execstart statement ExecStart=/usr/bin/python3 /home/pi/rpi-power-monitor/power-monitor.py  Was changed to ExecStart=/usr/bin/python3 /home/pi/rpi_power_monitor/power_monitor.py)     (Hyphens and underscores)
Enable and reboot went without a problem

When I run    sudo systemctl status power-monitor  I get the following message.

Loaded: loaded (/etc/systemd/system/power-monitor.service; enabled; vendor present:enabled)
Active: failed (Result: resources) since (date and time)
Process: 382 ExecStart=/usr/bin/python3 /home/pi/rpi_power_monitor/rpi_power_monitor/power_monitor.py (code=exited, status=0/SUCCESS)
Main PID: 382 (code=exited, status=0/SUCCESS)
CPU: 4.566s

Feb 09 17:34:23 rpipowermonitor systemd[1]: power-monitor.service: Failed to schedule restart job:Unit docker.service not found
Feb 09 17:34:23 rpipowermonitor systemd[1]: power-monitor.service: Failed with result 'resources'
Feb 09 17:34:23 rpipowermonitor systemd[1]: power-monitor.service: Consumed 4.566s CPU time.

I would love to help with testing the 0.3 beta but as you can tell I am pretty new to this so I am nervous I will cause you more headaches than help! Regards Simon
P.S.  I am using your custom PI OS image on a Raspberry 3.

David00, 2023-02-09:
Hi @Cube3SGM, no problem!

What you described above appears to be a documentation issue! I had forgotten to remove the docker dependencies from the "running as a service" page in the Wiki. I just made the changes to that page, but essentially, just edit `/etc/systemd/system/power-monitor.service` again, and remove these two lines:

	After=docker.service
	Requires=docker.service

I'm sure you'll do just fine in testing the 0.3 beta! Don't worry about causing more headaches than help - I want the documentation to be easy to follow for beginners too, so if you go through the steps and have trouble or something doesn't make sense, feel free to let me know and I'll do my best to help you out and also see if any improvements can be made.

If you want to get started on the v0.3.0 beta (from the current v0.2.0 custom OS image), have a look at the upgrade instructions on the `v0.3.0-beta` release page here:
https://github.com/David00/rpi-power-monitor/releases/tag/v0.3.0-beta

Cube3SGM, 2023-02-11:
Hi David,
All is working now on the bench and test loads... Fantastic
One small issue I had when configuring Grafana,  Section 3 Building your Dashboard.  In dashboard option, it points to two dashboard with screenshots and JSON files. This is where I went to load a dashboard into Grafana as instructed but the Links return a 404 page.  I subsequently realised that in your default OS image they are pre-loaded. So I am fine, its just a heads up.  Now I will prepare another SD card and have a run at 0.3 beta.   Thanks for your help. Regards Simon

David00, 2023-02-11:
>  All is working now on the bench and test loads... Fantastic

Awesome!

> One small issue I had when configuring Grafana, Section 3 Building your Dashboard. In dashboard option, it points to two dashboard with screenshots and JSON files. This is where I went to load a dashboard into Grafana as instructed but the Links return a 404 page. I subsequently realised that in your default OS image they are pre-loaded. So I am fine, its just a heads up.

Thanks for letting me know. I just fixed those links.

> Now I will prepare another SD card and have a run at 0.3 beta. Thanks for your help. Regards Simon

Thank you for checking it out! I'd love to hear your feedback on it in the discussion thread: https://github.com/David00/rpi-power-monitor/discussions/88

David00, 2023-03-29:
This has been completed and integrated into v0.3.0, which will be releasing soon.

Closed 2023-03-29.

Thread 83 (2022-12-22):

power_monitor.py not importing from config.py

jmadden91, 2022-12-22:
Hi David,

I'm having an issue since updating to release 0.2. Power_monitor.py does not seem to be importing from config.py, but at the same time I can't work out where the 125v default seems to be coming from. As you can see below, I've updated my config.py GRID_VOLTAGE to 1000v, but the program still shows 125v.

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

If I make the adjustment in line 35 of power_monitor.py it works correctly, however I assume its also not importing any of the calibration data either..

David00, 2022-12-22:
Did you re-install the module with pip after updating config.py? I know it's not intuitive, but it currently needs to be reinstalled after every modification to config.py for the changes to take effect:

    cd ~/rpi_power_monitor
    pip install .

I consider this a functional issue and have plans to resolve it via issue #75.

I also just updated the "Calibrating for Accuracy" page to reflect this step, as it was missing in step 6 of the Final Accuracy Calibration part.

jmadden91, 2022-12-22:
Ah, thats fixed it. Perfect, thanks for your help!

Cube3SGM, 2023-02-07:
Hello,  I have a similar problem related to the config.py when setting up for the calibration.

After modifying the config.py (236v and 10.1v) I am unable to successfully complete "pip install"  I receive the message
Defaulting to user installation because normal site-packages is not writable
ERROR: You must give at least one requirement to install (see "pip help install")

Any help appreciated, Regards Simon

Closed 2022-12-22.

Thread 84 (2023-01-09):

Rebooted Pi - Negative values , 0 values

ejg3855, 2023-01-09:
I had to reboot my pi and the power for the daughter board, and since then I have lost all semblance of reasonable data. This is not the first time I have unplugged the device but its the first time its thrown bizarre data.

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

David00, 2023-01-09:
Can you generate a debug plot and share a screenshot of it here?

https://github.com/David00/rpi-power-monitor/wiki/Software-1.-Overview#debug-mode

David00, 2023-01-10:
Thanks. Two things - the sample rate was a little bit low, which suggests you might have grabbed the debug plot with the power monitor still running in the background, OR, your Pi updated over the reboot and bumped up your kernel version.

The second thing is that I don't see any data coming in from any CTs. Only from the AC voltage input.

Can you do a `pip freeze | grep spidev`, and see if it shows `spidev==3.6`? If it's not 3.6, you'll need to update with `pip install spidev==3.6`.

This won't solve the issue of no data, but it will help the sample rate, at least.  For the issue of no data, can you double-check your CT wiring and connections?

ejg3855, 2023-01-16:
havent done the above, but i didnt plug the cable back in. I have data but its negative.

David00, 2023-01-21:
I'm not sure I understand. Are you saying that the problem was that you did not plug the cable back in?

ejg3855, 2023-01-21:
That was the lack of data problem, I am not sure why all the values are
suddenly negative tho.

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

Closed 2023-03-25.

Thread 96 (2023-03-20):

AC Voltage off

shingle01, 2023-03-20:
This might be a case of but the pre-assembled kit stupid, but living in Australia I found a self build more economical.

I have the 0.2 image rpi image installed.

9VAC supply attached, no CT clamps connected.  I've added the initial mains and transformer voltages to the config and ran:` pip install .`

No AC voltage correction value yet but the readings are 10% off and wildly erratic vs the kill'o'watt output.

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

No problems with the 3.3VDC supply.  The Voltage on PIN5 of ADC is a steady 1.89VDC.

Below is a debug output.  Strangely, despite CT1 being discounted I have a trend.

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

When AC supply is disconnected:
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

David00, 2023-03-20:
Hi @shingle01, I can tell from the debug graph that something isn't quite right with the bias_v output because all of the channels should be "idling" right around 511 in the plot.  Also, the trace that is showing up for CT1 looks very similar to a capacitor charge/discharge cycle.

I would suggest double-checking everything in the "Bias Voltage Reference" part of [the schematic](https://raw.githubusercontent.com/David00/rpi-power-monitor/docs/_includes/resources/Schematics/latest.png), and confirming the value (and capacitor type) for the filtering capacitors C0 - C3, C4, C5,

shingle01, 2023-03-22:
Thanks for the Info.

I replaced C5 with a polarized cap (store originally gave me non-polarized).  No Luck.

Added some more solder to the legs of U1, FIXED!

Thanks for the help.

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

David00, 2023-03-23:
Ok, great! I'm going to close this now, but feel free to reply in the future.

Closed 2023-03-23.

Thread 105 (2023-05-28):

3.0 update still gives negative wattage readings

emersonsc, 2023-05-28:
I recalibrated everything, made sure all of the cts are installed correctly. My two 60a clamps show negative wattage when the breakers are turned off or when there is no load. My circuit for my air compressor, for example, shows shows -2.7w when the compressor isnt running, but shows 2400w when running. I made sure the calibration was done correctly, and everything reads as it should.

jmadden91, 2023-05-29:
Might not address the true problem, but if its reading correctly when you are drawing current, you could use the watts_cutoff_threshold, to remove this. Eg, setting this to watts_cutoff_threshold=1 will zero it out. [https://david00.github.io/rpi-power-monitor/docs/v0.3.0/configuration.html#current_transformerschannel_](url)

David00, 2023-05-29:
It could be some noise coming in via the sensor wires.  If you disconnect the CT from the PCB, does the -2.7W go away? If so, that would confirm the noise suspicion, and you can try to move the sensor wires further away from any high voltage lines and/or change the path they're ran.

Thanks @jmadden91 for suggesting that. I was going to do the same. Here's the link to the relevant section in the docs:

https://david00.github.io/rpi-power-monitor/docs/v0.3.0/configuration.html#watts_cutoff_threshold

emersonsc, 2023-06-12:
Changing the value to 1 or even 2 didnt change anything, im still getting negative values reported. Its ONLY on the 60a CTs i have. My 20a, 30a, and 100a sensors dont give negative values with there is no load.

[config.txt](https://github.com/David00/rpi-power-monitor/files/11716336/config.txt)

vulture2600, 2023-07-02:
I am also getting this issue, but only when my central AC is on. I have 4 CT's, one on each main leg and one on each sub leg.
When the AC is off, and theres minimal load on the sub leg, it shows positive wattage. When the AC is ON, and theres minimal load on sub leg goes negative.

emersonsc, 2023-09-11:
> I am also getting this issue, but only when my central AC is on. I have 4 CT's, one on each main leg and one on each sub leg. When the AC is off, and theres minimal load on the sub leg, it shows positive wattage. When the AC is ON, and theres minimal load on sub leg goes negative.
>
> Edit: I'm noticing that the amps is still positive but the watts is negative.

I took an still having this issue with any circuit that has no load. It's very strange. I have tuned all of the clamps per the instructions but still have this issue

David00, 2023-09-11:
My suspicion is still noise coming in via the CT lead, especially because AC units draw a large current (which produces a larger magnetic field).

What value are you seeing reported? In the config.txt file you shared above, I see a `watts_cutoff_theshold` value of 2, which will only take effect if the readings are between -1.99 through 1.99.  If  you see anything outside this window, you'll have to increase the setting for watts_cutoff_threshold, or, you can set `enabled = false` for the channels you're not using.

Closed 2024-02-04.

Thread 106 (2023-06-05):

"two_pole" configuration incorrectly doubles current

cgleggett, 2023-06-05:
When a CT is marked as "two_pole" in the configuration file, ie the CT is metering one leg of a two pole breaker, both the power and current values are doubled. I don't think this is correct - it should be just the power that's doubled.

David00, 2023-06-06:
Hi @cgleggett, thanks for opening this issue for discussion.

The `two_pole` setting is essentially saying: If you had a sensor on each leg of a North American 240V circuit, what would the total power and the total current look like?

The `two_pole` setting assumes that the device connected to the 240V circuit distributes the amperage evenly over both legs, which is why the amperage is doubled. This is usually the case for solar inverters and EV chargers.

There may be an opportunity here to improve the docs surrounding the `two_pole` setting.

cgleggett, 2023-06-06:
Right, but if you've say, 20A running through one leg of a 240V circuit with no neutral, like an inverter, you have 20A running through the other. And while the power would be 2 x 120 x 20, the current is still 20A. If you're looking at the current of the circuit in say the grafana plot, the value will be twice what you would expect, though the power is correct.

David00, 2023-06-07:
I see what you mean now! Thanks for explaining further.  I'll have to look into how I can fix this in a way that makes sense for all types of grids.

David00, 2024-02-04:
This has been resolved now - thanks for reporting the issue!

Closed 2024-02-04.

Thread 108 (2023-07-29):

V1.2 PCB Resistor Values and Positions

misterjtc, 2023-07-29:
So I bought a DIY kit a really long time ago (April 2021) and I am just getting to putting it together now.

The documentation is a bit confusing as I only have 4X 22 ohm resistors in my kit and therefore am short 2 based on the docs.

The parts list also doesn't show a 10k ohm resistor but its shown in the assembly guide.

Anyways, it looks like instead of the 2X 22 ohm resistors, I ended up with 2X 10 ohm resistors which I have installed in R0 and R1 positions. Is this correct or do I need to get 2X 22 ohm resistors and install them in R0 and R1?

David00, 2023-07-29:
Hey @misterjtc, that's great you're now getting around to putting it together!  Quite a bit has changed since then - for the better!

One thing to note is that the latest v0.3.0 software has the channel numbers renamed from CT0 - 5 to CT1 - 6.  If your order included a paper printout with some instructions to get started, it is likely referring to the old CT0-5 numbering scheme. The [Assembly page in the Wiki](https://github.com/David00/rpi-power-monitor/wiki/Hardware-Assembly) has the latest assembly instructions.

In 2021, certain CT sensors required specific resistor values.  Since then, I have expanded my custom sensor lineup so that they all require the same 22 Ω resistor. This is why the latest docs only mention the 22 Ω resistor.

I checked your order, and the two 100A PZCT-02 sensors each need a 10 Ω resistor.  So, if you installed the two 10 Ω resistors in R0 and R1, you'll want to use the PZCT-02 sensors on channels CT1 and CT2, which correspond to the orange and green pairs in a cat5e cable.

Feel free to reach back out here if you have any more questions about the assembly, or shoot me an email at github at dalbrecht.tech.

misterjtc, 2023-07-29:
Hey @David00, thanks a lot for the quick and detailed reply!

I am glad I asked because I am working on the cat cable right now! This makes everything more clear, thank you.

Closed 2023-07-31.

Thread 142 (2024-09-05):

Accounting for phase shift

TaylorTWBrown, 2024-09-05:
I'm really interested in what this project has to offer, and I'll be buying a Pi soon to get started. However, I'm curious if there are methods to avoid needing phase correction.

For example, could the script read from two different ADCs simultaneously (one for voltage, the other with a CT clamp) to obtain a more accurate power factor reading and eliminate phase shift? From my reading, this could be done by using a common clock signal between two MCP3008 chips. Perhaps I'm overthinking something that isn't necessary. Thoughts?

David00, 2024-09-05:
Hey @TaylorTWBrown! The phase correction is no longer necessary (except for 3-phase, due to some limitations), and I suspect you may be reading the "old" docs here on the Github Wiki.  The current calibration process really only involves spot checking the readings to make sure they match a handheld clamp meter and multimeter.

The dual ADC method is a good idea, but not quite necessary. Current and voltage measurements are taken as simultaneously as possible on the same ADC by reading the current measurement on a channel, followed by a voltage reading.

With an overall sample rate of about 37 kSPS, the delay between reading voltage and amperage sequentially on the same ADC only introduces about a 1 degree phase error at 60 Hz, and slightly less at 50 Hz. I've considered this 1 degree error acceptable at this level of power monitoring.

TaylorTWBrown, 2024-09-07:
Interesting; thank you for the clarification! I agree that 1 degree of accuracy is more than tolerable. Was there a specific code change that removed the need for calibration? I've been perusing the commits and can't figure out when the change was made.

David00, 2024-09-07:
No problem! The improvement came with the release of version 0.3.0:
https://github.com/David00/rpi-power-monitor/releases/tag/v0.3.0

Closed 2024-09-17.

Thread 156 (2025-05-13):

All CTs flipped polarity after a power fail restart.

jralls, 2025-05-13:
The breaker supplying my rpi tripped this morning and after the system restarted the polarities on all of the CTs are flipped. I tried restarting the service, no change. It's not a big deal to change the reversed setting in config.toml and restart, but it seems weird. Any idea what would cause that?

David00, 2025-05-13:
Hi @jralls, did you happen to unplug the 9V AC transformer and plug it back into the receptacle the opposite way? This is the only thing that would cause all the CTs to report opposite (because the voltage wave is now opposite from the way it was before with respect to all the CTs).

jralls, 2025-05-13:
Nope, I just reset the breaker.

jralls, 2025-05-13:
> is moving the 9V AC transformer to a different outlet that's tied to the other phase of your split-phase panel

Aha! I did do the equivalent of that: I changed the circuit that the outlet is on to one on the other leg.

Here's the screenshot, github won't let me attach an html file.

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

David00, 2025-05-13:
Great! That'll do it! So, you can fix the issue by turning your 9V AC transformer upside down in the outlet you moved it to. This reverses the prongs, which swaps the direction that the transformer sees from the grid, which will in turn reverse the sign on all of your CTs.

Your debug graph looks good, but I did notice that your 9V AC supply is getting clipped (see the flat line at the top/bottom of the AC Voltage traces). The power monitor PCB can handle somewhere around 10.5V AC on that input before clipping so I'd guess your AC transformer is putting out around 11V.  This isn't really a big deal (the power monitor PCB will be fine), but there is a tiny bit of accuracy being left on the table due to the clipped voltage signal.

jralls, 2025-05-13:
OK, thanks. 1% is negligible considering the 10-40% error compared to PG&E when usage or generation is low.

David00, 2025-05-14:
Sounds good!

> the 10-40% error compared to PG&E when usage or generation is low

Is this the inaccuracy percentage that you're seeing with the power monitor?

jralls, 2025-05-14:
It's the range of differences when the power is less than 1KW on a leg. Above that it tightens to about 2%. It's a bit of an eyeball figure based on a week's worth of hourly data. The really big swings happen around 7 AM and 7 PM when the house load closely matches the PV output, so only 4-6 times a day. Not enough samples yet to get a decent confidence interval.

IIUC it's expected behavior for CTs operating at <5% of their max current. It's also not really significant big picture because it's in the low power range so it only changes the daily number by a kWh or two out of 30-50.

Closed 2025-05-13.

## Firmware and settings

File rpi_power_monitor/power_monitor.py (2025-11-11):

#!/usr/bin/python
import csv
import logging
import os
import subprocess
import sys
import timeit
from datetime import datetime
from math import sqrt, cos
from socket import AF_INET, SOCK_DGRAM, socket, getaddrinfo
import ipaddress
from textwrap import dedent
from time import sleep
import tomli
import spidev
from prettytable import PrettyTable
import argparse
import pathlib
from multiprocessing import Manager, Event
import signal
from copy import deepcopy
import os

from plotting import plot_data
from influxdb import InfluxDBClient
from influxdb.exceptions import InfluxDBServerError

# Logging Config
logger = logging.getLogger('power_monitor')
logger.setLevel(logging.INFO)
ch = logging.StreamHandler(sys.stdout)
ch.setLevel(logging.INFO)
formatter = logging.Formatter('%(asctime)s : %(message)s', datefmt='%Y-%m-%d %H:%M:%S')
ch_formatter = logging.Formatter('%(levelname)s : %(message)s')
ch.setFormatter(ch_formatter)
logger.addHandler(ch)

module_root = pathlib.Path(__file__).parent

parser = argparse.ArgumentParser(description='Power Monitor CLI Interface', epilog='Please see the project documentation at https://github.com/david00/rpi-power-monitor#readme for further usage instructions.')
parser.add_argument('--mode', type=str, help="Operating Mode. Defaults to 'main' if not specified.", default='main', required=False, choices=['main', 'terminal', 'plot'])
parser.add_argument('--samples', type=int, help="Optionally specify the number of samples to capture in plot mode.", required=False)
parser.add_argument('--title', type=str, help="Optionally specify the title of the generated plot.", required=False)
parser.add_argument('--config', type=pathlib.Path, help='path to config.toml file.', default= os.path.join(module_root, 'config.toml'), required=False)
parser.add_argument('-v', '--verbose', help='Increases verbosity of program output.', action='store_true')
parser.add_argument('-V', '--version', help='Displays the power monitor software version and exits.', action='store_true')

# Retention Policy Settings
retention_policies = {
    'rp_5min' : {
        'duration' : 'INF'
    },
    'autogen' : {      # This is the default retention policy.
        'duration' : '30d'
    }
}




class RPiPowerMonitor:
    """ Class to take readings from the MCP3008 and calculate power """
    def __init__(self, mode='main', config='rpi_power_monitor/config.toml', spi=None):
        self.pid = os.getpid()
        self.imported_plugins = dict()
        
        duplicate = self.check_dup_process()
        if duplicate:
            self.cleanup()

        self.load_config(config)
        
        if spi:
            self.spi = spi
        else:
            self.spi = spidev.SpiDev()
            self.spi.open(0, 0)
            self.spi.max_speed_hz = 1750000
        
        # Get DB Client
        self.get_db_client()
        if not self.client:
            logger.error(f"Failed to connect to InfluxDB server at {self.config['database']['host']}:{self.config['database']['port']}. Please make sure it's reachable and try again.")
            self.cleanup(-1)
        
        # Other Initializations
        # Validate continuous queries and retention policies
        self.validate_rps()
        self.validate_cqs()        
        self.points_buffer = [] # A buffer to hold sublists of points so that they can be written altogether (reduces DB overhead)
        self.def_cal = 0.88     # This is the default calibration factor for all CTs from my shop.
        self.terminal_mode = False
        self.PF_DELTA = 20      # This value enforces a minimum amperage waveform quality in order to calculate PF. 
                                # If the measured waveform peak-trough delta is less than this value, PF will not be calculated and will be set to zero.

        # Plugin Loading
        if self.config.get('plugins') is not None:
            self.load_plugins(self.config.get('plugins'))   # Note: Plugins are initialized here, but they are only started when the power monitor routine starts.

    
    def validate_cqs(self):
        '''Ensures that the continuous queries exist in the configured Influx database, and creates them if not.'''

        retention_policies = {
            '5m' : 'rp_5min'
        }

        try:
            db_name = self.config['database']['database_name']
            cqs = self.client.get_list_continuous_queries()
            existing_cqs = []
            for db in cqs:
                if db_name in db.keys():
                    if len(db[db_name]) > 0:
                        existing_cqs = [cq['name'] for cq in db[db_name]]
            
            # Home Power, Energy
            if 'cq_home_power_5m' not in existing_cqs:
                for duration, rp_name in retention_policies.items():
                    self.client.create_continuous_query(f'cq_home_power_{duration}', f'SELECT mean("power") AS "power", mean("current") AS "current" INTO "{rp_name}"."home_load_{duration}" FROM "home_load" GROUP BY time({duration})')
                    logger.debug(f"Created continuous query: cq_home_power_{duration}")
            
            if 'cq_home_energy_5m' not in existing_cqs:
                for duration, rp_name in retention_policies.items():
                    self.client.create_continuous_query(f'cq_home_energy_{duration}', f'''SELECT integral("power") / 3600000 AS "energy" INTO "{rp_name}"."home_energy_{duration}" FROM "home_load" GROUP BY time({duration})''')
                    logger.debug(f"Created continuous query: cq_home_energy_{duration}")

            # Net Power, Energy
            if 'cq_net_power_5m' not in existing_cqs:
                for duration, rp_name in retention_policies.items():
                    self.client.create_continuous_query(f'cq_net_power_{duration}', f'SELECT mean("power") AS "power", mean("current") AS "current" INTO "{rp_name}"."net_power_{duration}" FROM "net" GROUP BY time({duration})')
                    logger.debug(f"Created continuous query: cq_net_power_{duration}")

            if 'cq_net_energy_5m' not in existing_cqs:
                for duration, rp_name in retention_policies.items():
                    self.client.create_continuous_query(f'cq_net_energy_{duration}', f'''SELECT integral("power") / 3600000 AS "energy" INTO "{rp_name}"."net_energy_{duration}" FROM "net" GROUP BY time({duration})''')
                    logger.debug(f"Created continuous query: cq_net_energy_{duration}")

            # Solar Power, Energy
            if 'cq_solar_power_5m' not in existing_cqs:
                for duration, rp_name in retention_policies.items():
                    self.client.create_continuous_query(f'cq_solar_power_{duration}', f'SELECT mean("power") AS "power", mean("current") AS "current" INTO "{rp_name}"."solar_power_{duration}" FROM "solar" GROUP BY time({duration})')
                    logger.debug(f"Created continuous query: cq_solar_power_{duration}")
            
            if 'cq_solar_energy_5m' not in existing_cqs:
                for duration, rp_name in retention_policies.items():
                    self.client.create_continuous_query(f'cq_solar_energy_{duration}', f'''SELECT integral("power") / 3600000 AS "energy" INTO "{rp_name}"."solar_energy_{duration}" FROM "solar" GROUP BY time({duration})''')
                    logger.debug(f"Created continuous query: cq_solar_energy_{duration}")

             # Individual CT Energies
            for chan in range(1, 7):
                if f'cq_ct{chan}_power_5m' not in existing_cqs:
                    for duration, rp_name in retention_policies.items():
                        self.client.create_continuous_query(f'cq_ct{chan}_power_{duration}', f'''SELECT mean("power") AS "power", mean("current") AS "current" INTO "{rp_name}"."ct{chan}_power_{duration}" FROM "raw_cts" WHERE "ct" = '{chan}' GROUP BY time({duration})''')
                        logger.debug(f"Created continuous query: cq_ct{chan}_power_{duration}")

                # Individual CT Power, Energy
                if f'cq_ct{chan}_energy_5m' not in existing_cqs:
                    for duration, rp_name in retention_policies.items():
                        self.client.create_continuous_query(f'cq_ct{chan}_energy_{duration}', f'''SELECT integral("power") / 3600000 AS "energy" INTO "{rp_name}"."ct{chan}_energy_{duration}" FROM "raw_cts" WHERE "ct" = '{chan}' GROUP BY time({duration})''')
                        logger.debug(f"Created continuous query: cq_ct{chan}_energy_{duration}")

        except Exception as e:
            logger.error(f"Failed to create one or more continuous queries. Message: {e}")
        
        return

    def validate_rps(self):
        '''Ensures that the retention policies exist in the configured Influx database, and creates them if not.'''

        # Validate retention policies and continuous queries.
        try:
            existing_rps = self.client.get_list_retention_policies()
            rp_names = [rp['name'] for rp in existing_rps]
        except Exception as e:
            logger.warning(f"Failed to retrieve InfluxDB Retention Policies. Is Influx running?")
            self.cleanup(-1)
        
        try:
            for rp in retention_policies.keys():
                if rp not in rp_names:
                    self.client.create_retention_policy(rp, retention_policies[rp]['duration'], 1, default = (True if rp == 'autogen' else False))
                    logger.debug(f"Created retention policy {rp}")
        except Exception as e:
            logger.warning("Failed to create one or more retention policies!")
        
        return

    def load_config(self, config_file=os.path.join(module_root, 'config.toml')):
        '''Loads the user's config.toml file and validates entries.'''

        logger.debug(f"Attempting to load config from {config_file}")
        invalid_settings = False
        if not os.path.exists(config_file): 
            logger.error("Could not find your config.toml file at rpi_power_monitor/config.toml. Please ensure it exists, or, provide the config file location with the -c flag when launching the program.")

        try:
            with open(config_file, 'rb') as f:
                config = tomli.load(f)
        except FileNotFoundError:
            self.cleanup(-1)
        
        except tomli.TOMLDecodeError:
            logger.warning("The file config.toml appears to have a TOML syntax error. Please run the config through a TOML validator, make corrections, and try again.")
            self.cleanup(-1)

        self.config = config
        self.grid_voltage = config.get('grid_voltage').get('grid_voltage')
        self.ac_transformer_output_voltage = config.get('grid_voltage').get('ac_transformer_output_voltage')
        self.voltage_calibration = config.get('grid_voltage').get('voltage_calibration')
        self.name = config['general'].get('name')

        # Enabled Channels
        self.enabled_channels = [int(channel.split('_')[-1]) for channel, settings in config['current_transformers'].items() if settings['enabled'] ]
        if len(self.enabled_channels) == 0:
            invalid_settings = True
            logger.warning("Invalid config file setting: No channels have been enabled!")
        else:
            logger.debug(f"Sampling enabled for {len(self.enabled_channels)} channels.")
        
        ADC_CHANNELS = {
            1 : 0,  # PCB channel # : ADC channel #
            2 : 1,
            3 : 2,
            4 : 3,
            5 : 6,
            6 : 7
            }

        self.enabled_adc_ct_channels = {pcb_chan : adc_chan for pcb_chan, adc_chan in ADC_CHANNELS.items() if pcb_chan in self.enabled_channels}

        # CT Type Check
        for ct_channel, settings in config['current_transformers'].items():
            if settings['type'] not in ('consumption', 'production', 'mains'):
                logger.warning(f"Invalid config file setting: 'type' for {ct_channel} should be 'consumption' or 'production', or 'mains'. It is currently set to: '{config['current_transformers'][ct_channel]['type']}'.")
                invalid_settings = True


        # Mains assignment
        self.mains_channels = [int(channel.split('_')[-1]) for channel, settings in config['current_transformers'].items() if settings['type'] == 'mains' and settings['enabled'] == True]
        if len(self.mains_channels) > 0:
            logger.debug(f"Identified mains channels: {self.mains_channels}")
        else:
            logger.debug("No mains channels configured.")

        if invalid_settings:
            logger.critical("Invalid settings detected in config.toml. Please review any warning messages above and correct the issue.")
            self.cleanup(-1)

        # Production sources assignment
        self.production_channels = [int(channel.split('_')[-1]) for channel, settings in config['current_transformers'].items() if settings['type'] == 'production' and settings['enabled'] == True]
        logger.debug(f"Identified {len(self.production_channels)} production channels: ({self.production_channels})")
    
        # Consumption sources assignment
        self.consumption_channels = [int(channel.split('_')[-1]) for channel, settings in config['current_transformers'].items() if settings['type'] == 'consumption' and settings['enabled'] == True]
        logger.debug(f"Identified {len(self.consumption_channels)} consumption channels: ({self.consumption_channels})")

        # Two-pole validation
        for channel, settings in config['current_transformers'].items():
            if 'two_pole' not in settings.keys():
                logger.critical(f"{channel.capitalize()} is missing the two_pole setting in the config file. Please make sure the config has an entry for 'two_pole' and try again.")
                self.cleanup(-1)
        
        # Software Filter validation
        for channel, settings in config['current_transformers'].items():
            # Check for presence of amps_cutoff_threshold setting
            if 'amps_cutoff_threshold' not in settings.keys():
                logger.warning(f"{channel.capitalize()} is missing the amps_cutoff_threshold setting in the config file. While this isn't required, this featuer is helpful for removing noise when loads are off.")
                continue
            # Check to make sure that amps_cutoff_threshold is a number
            try:
                float(settings['amps_cutoff_threshold'])
            except ValueError:
                logger.critical(f"The value of {channel.capitalize()}'s amps_cutoff_threshold must be a number. Please correct this in your config.toml file and relaunch the software.")
                self.cleanup(-1)
            
            # Provide deprecation notice to watts_cutoff_threshold
            if 'watts_cutoff_threshold' in settings.keys():
                logger.warning("The watts_cutoff_threshold setting is deprecated and will be removed in a future release. Please utilize the `amps_cutoff_threshold` instead.")
                
            else:   # watts_cutoff_threshold is not in settings
                continue
            # Check that watts_cutoff_threshold is a number
            try:
                float(settings['watts_cutoff_threshold'])
            except ValueError:
                logger.critical(f"The value of {channel.capitalize()}'s watts_cutoff_threshold must be a number. Please correct this in your config.toml file and relaunch the software.")
                self.cleanup(-1)
            
            
            

    def get_db_client(self):
        '''Creates an InfluxDB Client using the loaded configuration.'''

        host = self.config['database']['host']
        port = self.config['database']['port']
        logger.debug(f"Trying to connect to the Influx database at {host}:{port}...")

        # Validate DB Settings
        db_host_valid = True
        try:
            host = host
        except ipaddress.AddressValueError:
            logger.debug(f'DB host does not look like an IP address. Testing DNS resolution...')
            pass
        try:
            ip = getaddrinfo(host, None)
        except Exception as e:
            logger.debug(f'Failed to translate database host to IP. Exception msg: {e}')
            db_host_valid = False
        
        if not db_host_valid:
            logger.warning(dedent(
                f"It appears that the database host value of {host} is not a valid IP or DNS name.  Or, DNS name resolution failed. Please check this setting and your networking settings and try again."))
            self.cleanup(-1)

        try:
            client = InfluxDBClient(
                host=host,
                port=port,
                username=self.config['database']['username'],
                password=self.config['database']['password'],
                database=self.config['database']['database_name'],
                timeout=7,
                retries=2)
            self.client = client

        except Exception as e:
            logger.warning(f"Failed to connect to InfluxDB database at {host}:{port}")
            self.client = None
            self.cleanup(-1)

        # Test Client
        try:
            self.client.create_database(self.config['database']['database_name'])
        except ConnectionRefusedError:
            logger.warning("DB connection refused - is Influx running?")
            self.cleanup(-1)
        except Exception as e:
            logger.warning(f"Failed to connect to the Influx database at {host}:{port}.")
            logger.debug(f"Error message:\n{e}")
            self.cleanup(-1)
        
        logger.debug(f"Successfully connected to Influx at {host}:{port}")
        return
        

    def dump_data(self, dump_type, samples):
        """ Writes raw data to a CSV file titled 'data-dump-<current_time>.csv' """
        speed_kHz = self.spi.max_speed_hz / 1000
        now = datetime.now().strftime('%m-%d-%Y-%H-%M')
        filename = f'data-dump-{now}.csv'
        with open(filename, 'w') as f:
            headers = ["Sample#", "ct1", "ct2", "ct3", "ct4", "ct5", "ct6", "voltage"]
            writer = csv.writer(f)
            writer.writerow(headers)
            # samples contains lists for each data sample.
            for i in range(0, len(samples[0])):
                ct1_data = samples[0]
                ct2_data = samples[1]
                ct3_data = samples[2]
                ct4_data = samples[3]
                ct5_data = samples[4]
                ct6_data = samples[5]
                v_data = samples[-1]
                writer.writerow([i, ct1_data[i], ct2_data[i], ct3_data[i], ct4_data[i], ct5_data[i], ct6_data[i], v_data[i]])
        logger.info(f"CSV written to {filename}.")

    def get_board_voltage(self):
        """ Take 10 sample readings and return the average board voltage from the +3.3V rail. """
        samples = []
        while len(samples) <= 10:
            data = self.read_adc(4) # channel 4 is the 3.3V ref voltage
            samples.append(data)

        avg_reading = sum(samples) / len(samples)
        board_voltage = (avg_reading / 1024) * 3.31 * 2
        return board_voltage

    def read_adc(self, adc_num):
        """ Read SPI data from the MCP3008, 8 channels in total. """
        r = self.spi.xfer2([1, 8 + adc_num << 4, 0])
        data = ((r[1] & 3) << 8) + r[2]
        return data

    def collect_data(self, num_samples):
        """  Takes <num_samples> readings from the ADC for each ADC channel and returns a dictionary containing the CT channel number as the key, and a list of that channel's sample data.
        
        Arguments:
        num_samples -- int, the number of samples to collect for each channel.

        Returns a dictionary where the keys are ct1 - ct6, voltage, and time, and the value of each key is a list of that channel's samples (except for 'time', which is a UTC datetime)
        """
        now = datetime.utcnow()  # Get time of reading

        samples = dict()
        for pcb_chan in self.enabled_channels:
            samples[f'ct{pcb_chan}'] = []
            samples[f'v{pcb_chan}'] = []

        start = timeit.default_timer()
        for _ in range(num_samples):
            for pcb_chan, adc_chan in self.enabled_adc_ct_channels.items():
                samples[f'ct{pcb_chan}'].append(self.read_adc(adc_chan))
                samples[f'v{pcb_chan}'].append(self.read_adc(5))
        stop = timeit.default_timer()
        duration = stop - start
       
        samples['time'] = now
        samples['duration'] = duration
        return samples

    def calculate_power(self, samples, board_voltage):
        """ Calculates amperage, real power, power factor, and voltage
        
        Arguments:
        samples -- dict, a dictionary containing lists of each channel's sample data, and a voltage wave that's been collected for each corresponding channel.
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

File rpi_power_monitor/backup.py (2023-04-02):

# This script will backup your power monitor database from InfluxDB. 
# If you are using a remote InfluxDB server (as in, not on your Raspberry Pi), you should not run this script, because
# it stops the power monitor in order to generate the backup.

# Backup settings are configured in rpi-power-monitor/rpi_power_monitor/config.toml

import os
import subprocess
from glob import glob
from datetime import datetime
import tomli
import argparse
import logging
import logging.handlers
import pathlib
import shutil
from time import sleep
import timeit

# Logging Setup. Logs to file named backups.log and also to the console.
formatter = logging.Formatter(fmt='{asctime} - {levelname}: {message}', datefmt='%m-%d-%Y %H:%M:%S', style='{')
ch = logging.StreamHandler()
ch.setLevel(logging.DEBUG)
ch.setFormatter(formatter)

module_root = pathlib.Path(__file__).parent
b_log = logging.getLogger(os.path.join(module_root, 'backup_logger'))
b_log.setLevel(logging.DEBUG)

rfh = logging.handlers.RotatingFileHandler('backups.log', backupCount=1)
rfh.setLevel(logging.DEBUG)
rfh.setFormatter(formatter)
b_log.addHandler(ch)
b_log.addHandler(rfh)

# Shell Colors
RED = '\033[0;31m'
YELLOW = '\033[0;33m'
ORANGE = '\033[38;5;214m'
GREEN = '\033[0;32m'
CYAN = '\033[0;36m'
NC = '\033[0m'

class Backup():
    '''Backup handler for Raspberry Pi Power Monitor.'''

    def __init__(self, settings):
        self.settings = settings
        b_log.info(f"\n{YELLOW}------------- Starting new backup -------------{NC}")

    def run(self, settings):
        '''Starts the Power Monitor backup process. 
        
        This function only handles the backup setup and config file backup; it determines if the host is using Docker or a native 
        installation of InfluxDB and calls either run_docker_backup() or run_native_backup() to execute the backup.
        '''

        start = timeit.default_timer()

        # Initialize backup constants.
        now = datetime.now().strftime('%Y-%m-%d_%H%M')
        create_and_mount_path(settings['device'], settings['mount_path'])
        backup_root = os.path.join(settings['mount_path'], self.settings['folder']) # like /media/backups/power_monitor_backups/
        this_backup_dir = os.path.join(backup_root, f'backup_{now}')    # like /media/backups/power_monitor_backups/backup_01-31-2023_0933)
        if not os.path.exists(this_backup_dir):
            os.makedirs(this_backup_dir)
            b_log.debug(f"Created directory {this_backup_dir}.")
        else:
            b_log.debug("Backup directory already exists.")

        # Backup config.toml
        shutil.copy2(settings['config_path'], this_backup_dir)
        # Stop Power Monitor service and backup InfluxDB
        r = subprocess.run('systemctl stop power-monitor.service', shell=True)
        b_log.info("Stopped power monitor service... Starting InfluxDB Backup. ")
        b_log.info("Please wait. This can take several minutes if you have a lot of data, and you won't see any output until it's done.")

        # Determine if this host is using Docker or a native InfluxDB installation.
        output = subprocess.run('docker ps | grep influxdb', shell=True, capture_output=True)
        if 'influxdb' in output.stdout.decode():
            # Docker container mode
            container_name = output.stdout.decode().split('   ')[-1].strip()
            print("Container name: ", container_name)
            print(f"Executing: docker exec {container_name} mkdir -p /backups/{this_backup_dir}'")
            subprocess.run(f'docker exec {container_name} mkdir -p /backups/{this_backup_dir}', shell=True)
            subprocess.run(f'docker exec {container_name} influxd backup -portable -database {settings["db_name"]} /backups/{this_backup_dir} > /dev/null', shell=True)
            b_log.info("Done backing up InfluxDB. Creating an archive...")
            r = subprocess.run(f'docker exec {container_name} tar -czf /backups/backup_{now}.tar.gz /backups/{this_backup_dir} > /dev/null 2>&1', shell=True)
            r = subprocess.run(f'docker cp {container_name}:/backups/backup_{now}.tar.gz {backup_root}', shell=True)
            b_log.debug("Done creating the archive. Cleaning up...")

            r = subprocess.run(f'docker exec {container_name} rm -r /backups/{this_backup_dir}', shell=True)
            r = subprocess.run(f'docker exec {container_name} rm -r /backups/backup_{now}.tar.gz', shell=True)

        else:
            # Natively installed InfluxDB mode - check to see if the configured database is localhost in order to continue.
            if settings['host'] not in ['localhost', '127.0.0.1', '127.0.1.1']:
                b_log.error(f"This script can only be used when InfluxDB is running locally on this Pi. Your configured database host is {settings['host']} which does not appear to be local to this Pi.")
                exit()

            r = subprocess.run(f'influxd backup -portable -database {settings["db_name"]} {this_backup_dir}/ > /dev/null', shell=True)
            b_log.info("Done backing up InfluxDB. Creating an archive...")
            # Create compressed archive
            r = subprocess.run(f'tar -czf {os.path.join(backup_root, f"backup_{now}.tar.gz")} {os.path.join(backup_root, f"backup_{now}")} > /dev/null 2>&1', shell=True)
            b_log.debug("Done creating the archive. Cleaning up...")
            # Cleanup
            subprocess.run(f'rm -r {this_backup_dir}', shell=True)

        # Check for backup_count limit
        existing_backups = glob(os.path.join(backup_root, 'backup_*.tar*'))
        existing_backups.sort(key=os.path.getmtime)

        if len(existing_backups) > settings['count']:
            b_log.info(f"There are currently {len(existing_backups)} backups. Removing {len(existing_backups) - settings['count']} old backups.")
            while len(existing_backups) > settings['count']:
                existing_backups.pop(0)
                subprocess.run(f'rm {existing_backups[0]}', shell=True)

        # Get filesize
        size = os.path.getsize(os.path.join(backup_root, f'backup_{now}.tar.gz'))
        size = size / 1E6   # Convert to MB
        
        # Unmount the drive
        r = subprocess.run(f"umount {settings['mount_path']}", shell=True, capture_output=True)
        if r.returncode == 0:
            b_log.debug("USB Drive unmounted.")
        else:
            b_log.debug(f"There was a problem unmounting your USB drive. Error message:\n{r.stderr.decode()}")


        stop = timeit.default_timer()
        duration = round(stop - start, 2)
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

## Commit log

2020-04-03 Added a phase calibration mode and the actual phase calibrations are done.
2020-04-05 Added fifth CT sensor (CT4) and tuned.
    Also readjusted the CT phase calibration to increase the accuracy just a bit more
2020-04-08 Added solar power override for sub-20 Watt readings
2020-04-13 Removed some print statements and added basic -h flag feedback
2020-07-01 Added code to support 6th current transformer
2020-07-02 Replaced all print statements with logging. Added new terminal launch mode to print the raw data to the terminal using a nicely formatted table. Updated requirements.txt
2020-07-03 Added additional calculations for CTs 4 & 5 in case this part of the code is needed in the future
2020-07-13 Added phase corrected plot and cleaned up some comments
    [plotting.py]
2020-07-23 Moved all user-defined settings to config.py, and... Removed the doubling of CT3's readings, which was a requirement for my personal implementation and is not likely going to be the case for most peo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
2020-07-28 Changed HTML report title from calibration result to phase-correction-result to align with the verbiage in the docs
2020-08-06 Refactor of v1.1 schematic. No Change in Netlist.
2020-08-26 Minor ehancements, including: - changed all CT input types to consumption - store RMS voltage to the DB - added underscores to replace spaces in HTML filenames - enhanced comments throughout
2020-08-28 Update BOM to include the 100nF capacitor for C4
    Fixes #13
    [LCSC_BOM-Minimal-v1.1.1.xlsx]
2020-09-11 These changes address issue #15. Database connectivity troubleshooting has been enhanced: The software will now attempt to restart the influxDB container if it is not running on initial startup. Also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
2020-11-17 Minor optimizations to ADC sampling function
2020-11-17 Added power factor storage to individual DB table. Fixes #20
2020-11-22 Added CT3 to the total current calculation - Fixes #21
2021-02-03 Moved documentation resources to separate branch as part of issue #26
    [LCSC_BOM-Minimal-v1.1.1.xlsx, LCSC_BOM-Minimal-v1.1.xlsx]
2022-05-24 fix spi init
2022-10-08 PR Review Changes Summary of changes: 1. Bumped version to 0.2.0 2. Removed sys import from influx_interface.py 3. Removed docker-py from requirements as it's no longer needed 4. Added/improved docst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
    [power_monitor.py]
2023-01-27 Major refactor to resolve #75 and #76. See comments... - Introduced a new configuration file (config.toml) to simplify the configuration and setup of the power monitor. It is kept outside of version 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
    [plotting.py, power_monitor.py]
2023-02-14 Fix the check to see if the power monitor is running in the background or not.
    [power_monitor.py]
2023-02-16 Fix negative mains reading, and improve the background process check
    [power_monitor.py]
2023-02-19 Add a 'reversed' configuration option to the config file to assist in correcting the summary figures like home power and net power
    [power_monitor.py]
2023-02-22 Add argument to allow the user to specify the number of samples used in plot mode
2023-03-09 Fix issue with backup.py failing to run
    [backup.py]
2023-03-29 Fix typo in debug logging output
    [power_monitor.py]
2023-04-03 Fix crash when user has channel 1 disabled
    [power_monitor.py]
2024-02-04 Fix import of plugin handler
    [power_monitor.py]
2024-02-04 Fix #106 by removing doubling of amperage for 2-pole channels
    [power_monitor.py]
2024-02-12 Adding the RPi 4 Model B Case (#121)
    [factory-assembled-hat-pi4-box.stl, factory-assembled-hat-pi4-cover.stl, factory-assembled-hat-pi4-standoffs.stl]
2024-03-05 Fix #123 by handling the config file's missing plugin section gracefully
    [plugin_handler.py, power_monitor.py]
2024-03-10 Fix plugin import issue. Also, add error handling to the mqtt plugin's initialization, and update mqtt plugin's readme to specify version 1.6.1.
    [plugin_handler.py]
2024-07-27 Fix logic when setting the amperage sign for channels with reversed = true
    [power_monitor.py]
2024-09-17 Fix sign on amperage values
    [power_monitor.py]
2024-09-24 Fix home consumption current and net current calculation when one or more CTs have two_pole = true
    [power_monitor.py]
2025-03-13 Fix amperage sign alternations when AC voltage input is not present
    [power_monitor.py]
2025-03-14 Bump version to v0.3.3 and fix issue with amps_cutoff_threshold
    [power_monitor.py]
2025-11-11 Fix bug with using amp_cutoff_threshold and bump version to 0.3.4
    [power_monitor.py]
